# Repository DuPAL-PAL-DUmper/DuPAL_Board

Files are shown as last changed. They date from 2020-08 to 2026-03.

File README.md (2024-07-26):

# DuPAL board

## DISCLAIMER

Any use of this project is **under your own responsibility**.
You will be responsible of checking the correct construction and functionality of your board and the compatiblity of the chips You will insert into it.
By using this project You will agree that I cannot be held responsible if it will destroy any of your devices, damage your computer, burn down your house or whatever.

**Do NOT come to me for hand-holding** using this. It is NOT a plug-and-play tool, and it is something I created **for my own use** and I released in case someone might have an use for it.

## Introduction

The DuPAL boards are tools meant to help in dumping/reversing the content of some PLDs and memories.

The original DuPAL revision 2, currently supported by most tools, but limited in support to PAL devices (with the exclusion of PAL22) can be found [here](https://github.com/DuPAL-PAL-DUmper/DuPAL_Board/tree/master/board/DuPal_DIP).

The [DuPAL V3](https://github.com/DuPAL-PAL-DUmper/DuPAL_Board/tree/master/board/DuPal_V3), AKA "dupico", has more potential and will eventually support a much larger number of devices, but most of the tools have not yet been ported to it. Adapter pods for the dupico can be found [here](https://github.com/DuPAL-PAL-DUmper/DuPAL_Board/tree/master/board/dupico_pods).

### Sponsorship

PCBWay_logo

This project is kindly sponsored by [PCBWay](https://pcbway.com).
PCBWay specializes in manufacturing high-quality PCBs and makes them affordable to hobbyist and professionals alike.

The range of services they offer include PCB prototyping, assembly, instant quotes for your order, a verification process by a team
of experts and an easy to use, hassle-free order process.

I'm grateful to PCBWay for the support in creating this project.

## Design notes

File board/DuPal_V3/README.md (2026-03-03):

# DuPAL V3 "dupico" board

## DISCLAIMER

Any use of this project is **under your own responsibility**.
You will be responsible of checking the correct construction and functionality of your board and the compatiblity of the chips You will insert into it.
By using this project You will agree that I cannot be held responsible if it will destroy any of your devices, damage your computer, burn down your house or whatever.

**Do NOT come to me for hand-holding** using this. It is NOT a plug-and-play tool, and it is something I created **for my own use** and I released in case someone might have an use for it.

## Introduction

The DuPAL V3, AKA "dupico" board is a simple circuit that mounts a Raspberry Pico (RP2040), 74HC595 SIPO registers, 74HCT166 PISO registers, and some glue logic and passives.

The board is designed to help me analyze and dump various types of PLDs and memories.

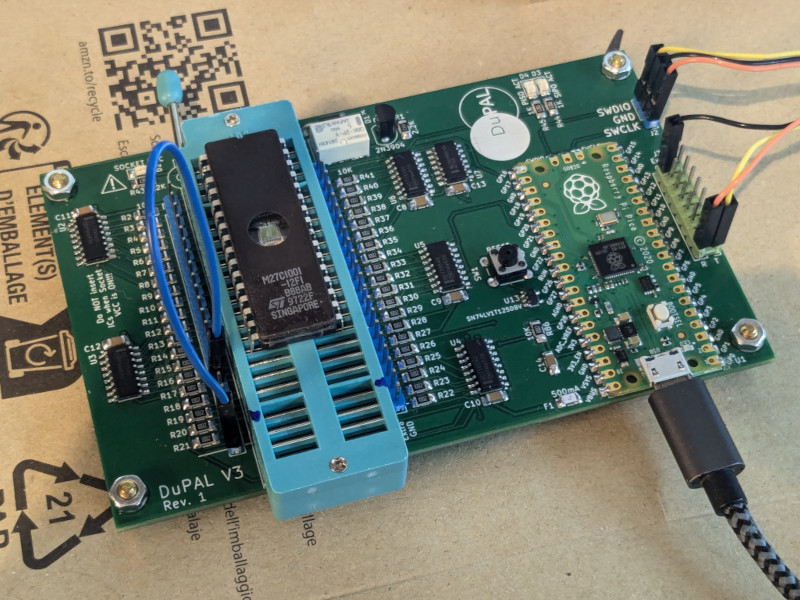
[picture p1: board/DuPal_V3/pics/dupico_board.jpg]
Rev. 1 PCB


Various adapters (or "pods") can be designed to suit different types of ICs. The pods will be plugged in the ZIF42 socket.

## Software

### Firmware

See [here](https://github.com/DuPAL-PAL-DUmper/dupico_firmware) for details.

### dpdumper

This is a generic dumper for combinatorial ICs. See [here](https://github.com/DuPAL-PAL-DUmper/dpdumper) for the repository.

## Hardware

The board was designed with [KiCad](https://kicad.org/) EDA.

In its current form, the board is relatively simple build, using through-hole and (non fine pitched) SMD components.

### Bill of Materials

| Component | Qty | Type / Value | Notes |
| --- | --- | --- | --- |
| C1, C3 - C14 | 13  | 100nF / 1206 / ceramic | |
| C2 |  1  | 10uF / 10V / 1206 / ceramic | |
| D1 |  1  | 1N5818 | |
| D2, D3, D4 |  3  | Your choice of 1206 SMD LEDs | |
| F1 |  1  | 1206 500mA fuse | https://www.mouser.it/ProductDetail/530-C1F500 |
| J1 |  1  | ZIF42 or ZIF48 socket, wide | If using ZIF42, leave the bottom 6 pins empty on the PCB |
| J2 |  1  | 1x3 header, 2.54mm pitch | |
| J3 |  1  | 2x8 header, 2.54mm pitch | |
| J4, J5 |  2  | 1x21 header, 2.54mm pitch | |
| K1 |  1  | Omron G6K-2P-Y-DC5 | https://www.mouser.it/ProductDetail/653-G6K-2P-Y-DC5 |
| Q1 |  1  | 2N3904 | |
| R1 |  1  | 2.2K / 1206 | |
| R2 - R41, R86 | 41  | 10K / 1206 | |
| R42, R46 - R85 | 41  | 470K / 1206 | |
| R43 - R45 |  3  | 1.2K / 1206 | |
| SW1 |  1  | Switch button 6mm | |
| U1 |  1  | Pi Pico | |
| U2 - U6 |  5  | 74HCT595 SOIC-16 | HCT variant is important |
| U7 |  1  | 74HCT02 SOIC-14 | HCT variant is important |
| U8 - U12 |  5  | 74HCT166 SOIC-16 | HCT variant is important |
| U13 |  1  | SN74LV1T125DBV SOT-23-5 | https://www.mouser.it/ProductDetail/595-74LV1T125DBVRG4  |

⚠️**WARNING:**⚠️ Note that U10, on the backside of the PCB, has the opposite orientation in respect to U8, U9, U11 and U12. This is NOT a mistake, trust the silkscreen in this case.

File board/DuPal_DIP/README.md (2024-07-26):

# DuPAL board

## DISCLAIMER

Any use of this project is **under your own responsibility**.
You will be responsible of checking the correct construction and functionality of your board and the compatiblity of the chips You will insert into it.
By using this project You will agree that I cannot be held responsible if it will destroy any of your devices, damage your computer, burn down your house or whatever.

**Do NOT come to me for hand-holding** using this. It is NOT a plug-and-play tool, and it is something I created **for my own use** and I released in case someone might have an use for it.

## Introduction

The DuPAL board is a simple circuit that mounts an AVR MCU (A classic ATmega328P of Arduino fame), three 74HC595 SIPO registers, one 74HCT166 PISO register, a MAX232 to adapt the serial port to RS232, a linear voltage regulator and a bunch of other passive components.

This board was designed and built to help myself bruteforce PAL devices. It has the hardware facilities necessary to scan all the inputs of the PAL, to check whether an output is high, low or hi-z and to report back the status to the host.

Details on how the features are implemented can be found on the Firmware's repository.

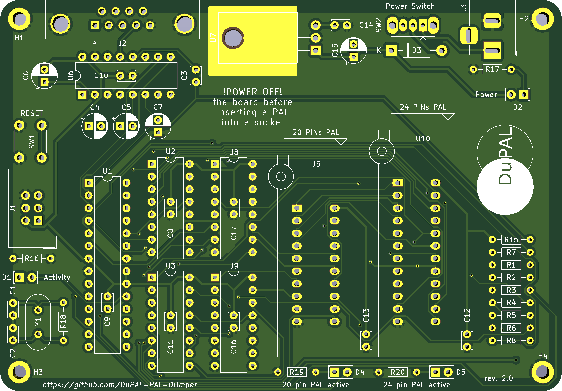
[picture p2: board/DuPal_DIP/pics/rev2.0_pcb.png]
Rev. 2.0 PCB


## Software

### Bootloader

This board uses the [Optiboot Bootloader](https://github.com/Optiboot/optiboot), currently at version 8.0, built for an **ATMega328** running at 20Mhz, and with a baudrate of 57600bps.

The command line to build the bootloader is

```shell
make atmega328 AVR_FREQ=20000000L LED_START_FLASHES=8 BAUD_RATE=57600
```

See [Compiling Optiboot](https://github.com/Optiboot/optiboot/wiki/CompilingOptiboot) for details.

The resulting bootloader can then be loaded via the ISP header. For example, by using `avrdude` and an **AVR Dragon** programmer:

```shell
avrdude  -c dragon_isp -P usb \
  -p atmega328p -e -u -U efuse:w:0xFD:m -U hfuse:w:0xDE:m \
  -U lfuse:w:0xFF:m -U flash:w:optiboot_atmega328.hex
```

### Firmware

Details on the firmware can be found on the **DuPAL_Firmware** repository.

## Hardware

The board was designed with [KiCad](https://kicad.org/) EDA.

In its current form, the board is a pretty simple build, using exclusively through-hole components.

### Powering the board

The board can be powered with a DC supply voltage between 7.5V and 9V, 12V is possible but the regulator starts to get hot.

The power connector has a positive tip, and is protected against reverse voltage by a 1N4001 diode.

### Bill of Materials

- **SW2** - Sliding SPST switch, pin spacing is 2mm, the outer 2 pins are just for mechanical stability
- **J1** - 3x2 pins 2.54mm pcb male header
- **C4, C5, C6 & C7** - 4x 1uF / 35v min electrolytic capacitors
- **C15** - 1x 0.22uF / 35v min electrolytic capacitor
- **C3, C8, C9, C10, C11, C12, C13, C14, C16, C17** - 10x 100nF ceramic bypass capacitors
- **C1 & C2** - 2x 22pF NP0 ceramic capacitors
- **R18** - 1x 1Mohm 1/4W resistor
- **R17** - 1x 1.2k 1/4W resistor
- **R16, R19 & R20** - 3x 680ohm 1/4W resistor
- **R1, R2, R3, R4, R5, R6, R7, R8 & R15**, 9x 10Kohm 1/4W resistors
- **D1, D2, D4 & D5** - 4x 3mm LED (recommended red for power, green for activity)
- **J3** - Power supply female barrel connector
- **J2** - DB9 female angled connector
- **SW1** - 4 pin push button
- **D3** - 1N4001 diode
- **U2, U3 & U9** - 3x 74HC595
- **U8** - 1x 74HCT166
- **U6** - MAX232
- **U7** - 7805 TO220 regulator
- **U1** - ATMega328p
- **Y1** - 20Mhz HC49 crystal
- **U5** - 20pin slim ZIF socket
- **U10** - 24pin slim ZIF socket
- *Heat sink for the power regulator (optional, but recommended)*
- *5x 16pin socket (optional)*
- *1x 28pin slim socket (optional)*

Thanks @Porchy for the updated BOM.

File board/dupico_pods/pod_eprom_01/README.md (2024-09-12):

# EPROM_01 POD for dupico

## DISCLAIMER

Any use of this project is **under your own responsibility**.
You will be responsible of checking the correct construction and functionality of your board and the compatiblity of the chips You will insert into it.
By using this project You will agree that I cannot be held responsible if it will destroy any of your devices, damage your computer, burn down your house or whatever.

**Do NOT come to me for hand-holding** using this. It is NOT a plug-and-play tool, and it is something I created **for my own use** and I released in case someone might have an use for it.

## Introduction

The EPROM_01 POD is an adapter for the DuPAL V3 (AKA "dupico") meant to support the most common 24/28/32 pin ROMs, the only requirement being that they can be powered by 5V, have GND in the lower left pin and VCC in the upper right.

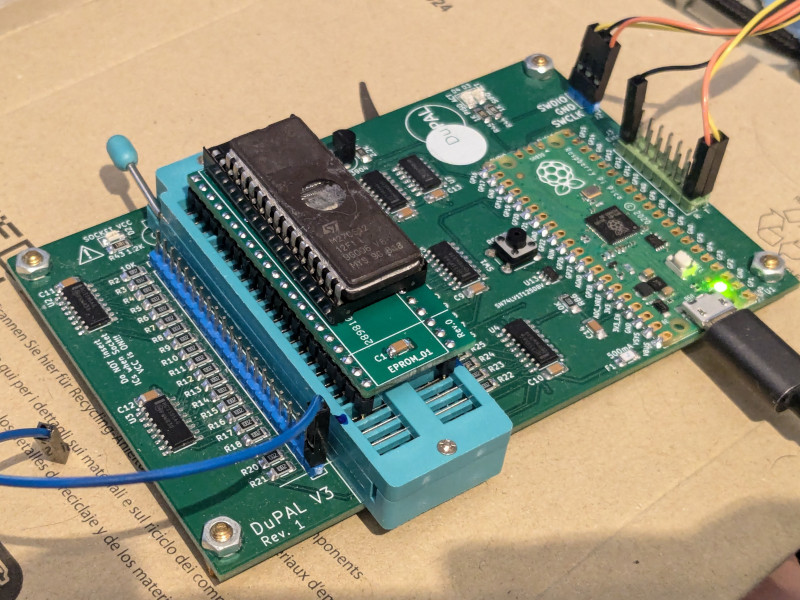
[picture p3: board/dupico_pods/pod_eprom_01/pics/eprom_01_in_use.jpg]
Rev. 0 PCB


### Usage

This device is inserted in the ZIF socket of the dupico: if you installed a ZIF42 socket, it will fill all the 42 pins, if you installed a 48 pin socket, make sure to leave the bottom 6 pins empty (fit this in the topmost part of the socket).

When you fit a ROM device in it, make sure to align it to the bottom of the pod socket (so, a 28 pin device will leave empty the topmost 4 pins in the socket). 

Pin 32 on the pod socket is **hardwired to VCC**, there are other 7 selectable pins that can provide power, configured with 3 pins on the **ZIF42** socket:

| 24 | 23 | 22 | -> | Powered Pin (32 pin socket) |
| -- | -- | -- | -- | --- |
|  0 |  0 |  0 | | 30 / 32 |
|  0 |  0 |  1 | | 28 / 32 |
|  0 |  1 |  0 | | 26 / 32 |
|  0 |  1 |  1 | | 25 / 32 |
|  1 |  0 |  0 | | 24 / 32 |
|  1 |  0 |  1 | | 23 / 32 |
|  1 |  1 |  0 | | 20 / 32 |
|  1 |  1 |  1 | | 32 only |

#### Socket connections

This drawing shows how the pin on the 32 socket are wired to the pins on the dupico's ZIF42.

```
            __ __
   1 ---> 1   U  32 <--- +5V (fixed)
   2 ---> 2      31 <-- 41
   3 ---> 3      30 <-- 40 --- Selectable +5V
   4 ---> 4      29 <-- 39
   5 ---> 5      28 <-- 38 --- Selectable +5V
   6 ---> 6      27 <-- 37
   7 ---> 7      26 <-- 36 --- Selectable +5V
   8 ---> 8      25 <-- 35 --- Selectable +5V
   9 ---> 9      24 <-- 34 --- Selectable +5V
  10 --> 10      23 <-- 33 --- Selectable +5V
  11 --> 11      22 <-- 32
  12 --->12      21 <-- 31
  13 --> 13      20 <-- 30 --- Selectable +5V
  14 --> 14      19 <-- 29
  15 --->15      18 <-- 28
GND ---> 16______17 <-- 27

```

## Hardware

The board was designed with [KiCad](https://kicad.org/) EDA.

In its current form, the board is relatively simple build, using through-hole and (non fine pitched) SMD components.

You can order the PCBs at [PCBWay](https://www.pcbway.com/project/shareproject/dupico_EPROM_01_POD_ed82b51c.html)!

### Bill of Materials

| Component | Qty | Type / Value | Notes |
| --- | --- | --- | --- |
| J1 |  2  | 21 pin 2.54mm headers | Use rounded pin headers to put less stress on dupico ZIF, snip the protruding part of the header |
| C1, C2 |  2  | 100nF / 1206 / ceramic | |
| Q1 - Q7 |  7  | MMBT3906 | |
| J2 |  1  | 32 pin wide socket | Solder this AFTER the two J1 headers, you can use a ZIF32 socket. |
| U2 |  1  | 74ACT138 SOIC-16 | |
| R1 - R7 |  7  | 1K / 1206 | |

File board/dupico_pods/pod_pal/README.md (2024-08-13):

# PAL POD for dupico

## DISCLAIMER

Any use of this project is **under your own responsibility**.
You will be responsible of checking the correct construction and functionality of your board and the compatiblity of the chips You will insert into it.
By using this project You will agree that I cannot be held responsible if it will destroy any of your devices, damage your computer, burn down your house or whatever.

**Do NOT come to me for hand-holding** using this. It is NOT a plug-and-play tool, and it is something I created **for my own use** and I released in case someone might have an use for it.

## Introduction

The PAL POD is an adapter for the DuPAL V3 (AKA "dupico") meant to support 20 and 24 pin PAL (and pinout compatible) devices.

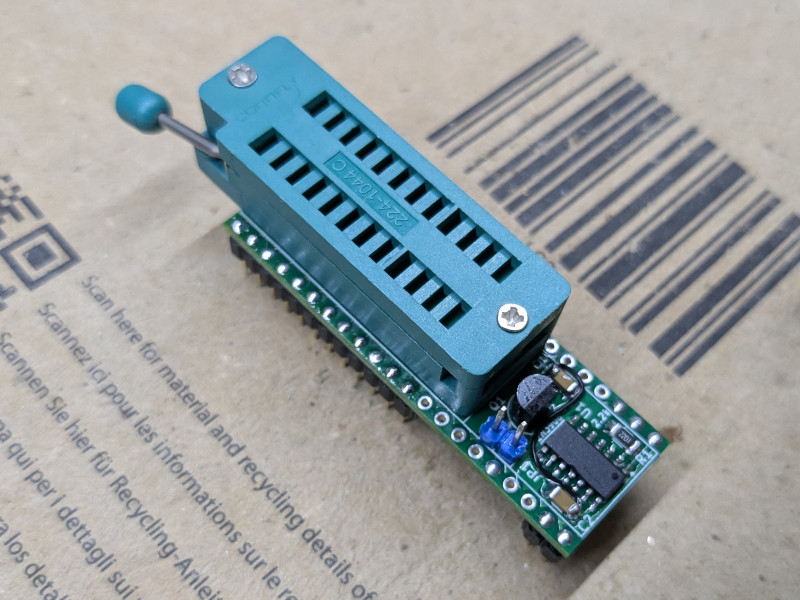
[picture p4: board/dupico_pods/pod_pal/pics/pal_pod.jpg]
Rev. 0 PCB


### Usage

This device is inserted in the ZIF socket of the dupico: if you installed a ZIF42 socket, it will fill all the 42 pins, if you installed a 48 pin socket, make sure to leave the bottom 6 pins empty (fit this in the topmost part of the socket).

When you fit a PAL device in it, make sure to align it to the bottom of the ZIF24 socket (so, a 20 pin device will leave empty the topmost 4 pins in the socket). 

**Pulling high pin 22 of the ZIF42 socket will turn on the transistor on the pod, which in turn will provide 5V to pin 22 of the ZIF24 socket**, pin 12 is hardwired to GND, and pin 24 to VCC.

Some old PAL/GAL devices require more current than the switching via pin 22 can provide. In these cases, close JP1 to bypass the transistor and provide 5V directly.

#### Socket connections

This drawing shows how the pin on the ZIF24 sockets are wired to the pins on the dupico's ZIF42.

```
            __ __
   1 ---> 1   U  24 <--- +5V
   2 ---> 2      23 <-- 41
   3 ---> 3      22 <-- 40 --- 5V if ZIF42 pin 22 is HIGH
   4 ---> 4      21 <-- 39     or JP1 closed
   5 ---> 5      20 <-- 38
   6 ---> 6      19 <-- 37
   7 ---> 7      18 <-- 36
   8 ---> 8      17 <-- 35
   9 ---> 9      16 <-- 34
  10 --> 10      15 <-- 33
  11 --> 11      14 <-- 32
GND ---> 12______13 <-- 31

```

## Hardware

The board was designed with [KiCad](https://kicad.org/) EDA.

In its current form, the board is relatively simple build, using through-hole and (non fine pitched) SMD components.

You can order the PCBs at [PCBWay](https://www.pcbway.com/project/shareproject/dupico_PAL_POD_06ceb24f.html)!

### Bill of Materials

| Component | Qty | Type / Value | Notes |
| --- | --- | --- | --- |
| J1 |  2  | 21 pin 2.54mm headers | Use rounded pin headers to put less stress on dupico ZIF |
| C1, C2 |  2  | 100nF / 1206 / ceramic | |
| JP1 |  1  | 2 pin 2.54mm header | Bypasses the transistor and provides direct 5V |
| Q1 |  1  | 2N3906 TO92 | |
| J2 |  1  | narrow ZIF24 socket | Solder this AFTER the two J1 headers |
| U1 |  1  | 74ACT04 SOIC-14 | |
| R1 |  1  | 1K / 1206 | |

If you wish to use a 74HCT04 for U1, use a 2.2K resistor for R1.

## Errata

- Rev. 0 requires a bodge wire, see changelog for details
- Rev. 0 and 1 have the footprint of 2N3906 reversed. With these revisions, you need to rotate the transistor in respect to the footprint!

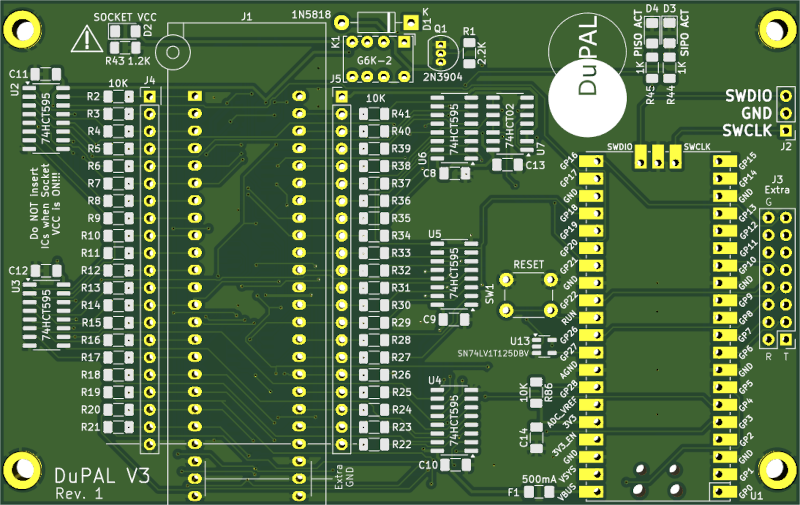
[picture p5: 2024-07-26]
board/DuPal_V3/pics/rev_1.png

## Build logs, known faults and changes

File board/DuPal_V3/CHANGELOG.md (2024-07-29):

# Board Revisions

## Rev. 2

No changes in schematic, rerouted some traces to avoid clearance violations.

## Rev. 1

First released design

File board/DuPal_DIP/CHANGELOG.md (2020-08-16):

# Board Revisions

## Rev. 2.0 (2020-08-??)

- Added support for 24 pin PALs
- Use shift registers for input
- Added LEDs to indicate activity on a socket

Rev. 2.0 PCB

## Rev. 1.1 (2020-08-15)

- Fixed the ugly silkscreen from rev.1

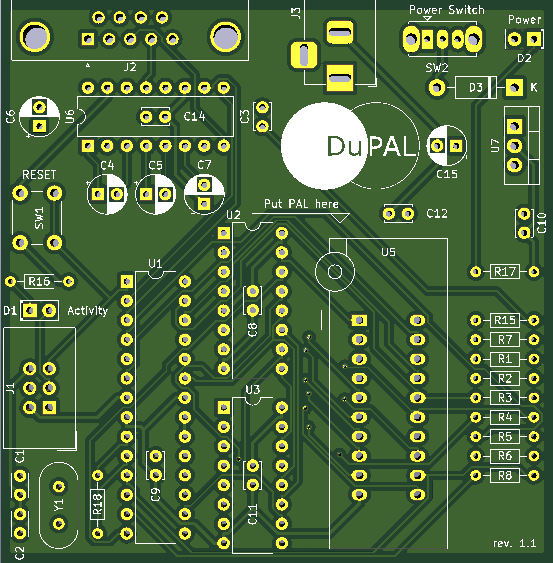
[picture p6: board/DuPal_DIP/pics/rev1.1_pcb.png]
Rev. 1.1 PCB


## Rev. 1 (2020-??-??)

First produced  version of the board, recognizable by a "rev.1" on the bottom right corner.

- Supports 20 pin PAL devices
- RS232 interfacing

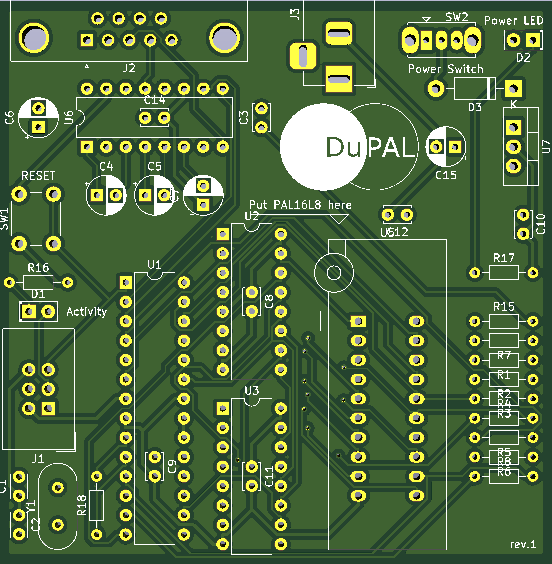
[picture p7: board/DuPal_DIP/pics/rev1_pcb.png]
Rev. 1 PCB


## Rev. 0 (2019-??-??)

First design, was never produced. Had some ICs too near to actually fit.

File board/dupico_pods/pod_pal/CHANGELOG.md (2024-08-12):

# PAL pod for Dupico

## Rev. 2

- Replaced R1 with 1K resistor
- Replaced 74HCT04 with 74ACT04
- Fixed 2N3906 orientation

## Rev. 1

- Fixed missing VCC trace 
- **WARNING:** 2N3906 is reversed!

## Rev. 0 - Initial release

- Initial release of the card
- Has a missing VCC trace to power the IC
- **WARNING:** 2N3906 is reversed!

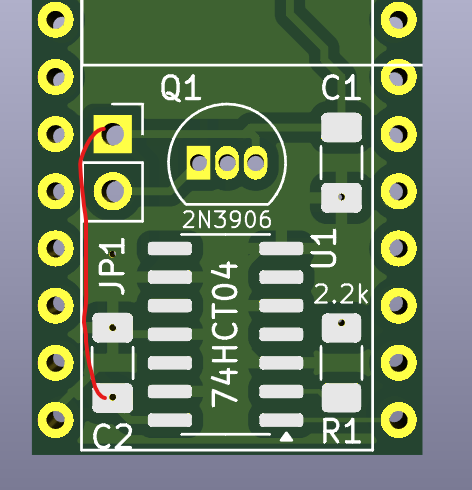
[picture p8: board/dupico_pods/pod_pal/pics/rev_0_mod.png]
Rev.0 Mod


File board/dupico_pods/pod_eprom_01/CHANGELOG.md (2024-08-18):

# EPROM_01 pod for Dupico

## Rev. 0 - Initial release

- Initial release of the card

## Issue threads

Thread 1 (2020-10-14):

Wrong Capacitor

toms001, 2020-10-14:
Hi, a very cool project!
1x 0.22uF / 35v min electrolytic capacitor (bom) at the 7805 or 220uF?
Thanks, toms001

hkzlab, 2020-10-14:
Hello, it's 0.22, but is also actually a non-critical value, as it is meant to smooth out the ingress from your power supply.
I myself used a 0.22uF in a build and a 0.47 in another because I had that one handy.
By all means, if you have a noisy psu increase it, even to 100uF if required.

toms001, 2020-10-19:
ok, thank you. A last question about the 74HC(T) - does it matter if i choose 74HC or 74HCT? In the schematics there is a 74HC166 and at your bom is 74HCT166 listed.

hkzlab, 2020-10-19:
Use an HCT for the 166, outputs from PALs that have TTL level signals will be picked up better.
You can use HC for the rest.

Closed 2020-10-14.

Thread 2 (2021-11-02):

Some issues with capacitors

dillix, 2021-11-02:
Hi, hkzlab! Thanks for cool project!

There is some issues with capacitors:
1) There is C5 electrolytic capacitor in BOM list. Can you provide it capacity?
2) I tried several types of through-hole ceramic bypass capacitors 100nF (C3, C8, C9, C10, C11, C12, C13, C14, C16, C17) , but all of them didn't fit under the cribs for chips, so I soldered smd ones. Can you provide a photo of your ones?

hkzlab, 2021-11-02:
Fixed missing C5. Use an 1uF. If in doubt, refer to the schematics in the kicad project.

For the 100nF caps, either
- Find sockets with a larger space in the middle
- Mount them on the underside of the board.

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

Closed 2021-11-02.

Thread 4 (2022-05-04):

Specifications for the switch

hexbus, 2022-05-04:
Greetings - do you have the specifications for the required switch?  i.e. spacing between pins, etc?

V/R,
Jon

hkzlab, 2022-05-05:
I can't give you a model: I've designed it to use some junk no-name switches I had around, though it should be pretty standard:
The pitch between the holes is 2mm.
Only the center and right inner pins are used and connected (looking at the board from the component side, keeping the power switch component up), the rest is for support.
So if you find a switch that fits on the external holes and the center one, just put a blob of solder to connect the outer support pins with the nearest smaller pad of the inner pins.

hexbus, 2022-05-05:
Great, that spacing helps me out quite a bit!  If you could please add the 2MM description to the BOM, I’ll let you know when I find a switch that works and give you the model!  Thanks!

hexbus, 2022-05-09:
I've found a few that work:

[First one from DigiKey - right angle](https://www.digikey.com/en/products/detail/c&k/OS102011MA1QN1/1981430)

[Second one from DigiKey - straight](https://www.digikey.com/en/products/detail/c-k/OS102011MS2QN1/411602)

These are both rated for 12V, but only .1A.  Not sure how much current is going through this switch - do you have any thoughts as to the specs?

I also found a bunch of these for cheap [on eBay](https://www.ebay.com/itm/182535742300).  Same switch, apparently.

hkzlab, 2022-05-10:
Hm, the component that will absorb the most, by far, will be the PAL you put on the board. I took some measurements years ago, but it seems I can't find where I put the notes. Current was usually slightly above the 100mA mark though.
Alas, none of the junk switches I used had markings on them.

You can also use the two external support units to connect the switch (4mm pitch) if you can't find something rated 0.2A, they're not connected to GND. You just need to put a blob of solder between the outer and the inner pins to restore connection (I actually did that on one of my protos).

Also, I usually use a lower voltage than 12, 7 or 8VDC is fine.

hexbus, 2022-05-10:
Yeah, the eBay ones I found didn’t have any marking either.  I’ll have to see how well it works :-)

I agree we need something more slightly beefier than a 0.1.  I’ll need to burn a protected PAL/GAL and see if the noname eBay switch holds up.

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

JohnDMcMaster, 2022-05-16:
I just went through a build exercise and could submit a reference BOM if it was accepted into the README

WIP can be seen here: https://twitter.com/johndmcmaster/status/1525758218961440768

hkzlab, 2022-05-16:
@JohnDMcMaster sure. Absolutely nothing against that.
Especially since life is really hectic for me now, so can't really work on this anymore for the foreseeable future, so every help is gladly accepted.

Closed 2022-11-08.

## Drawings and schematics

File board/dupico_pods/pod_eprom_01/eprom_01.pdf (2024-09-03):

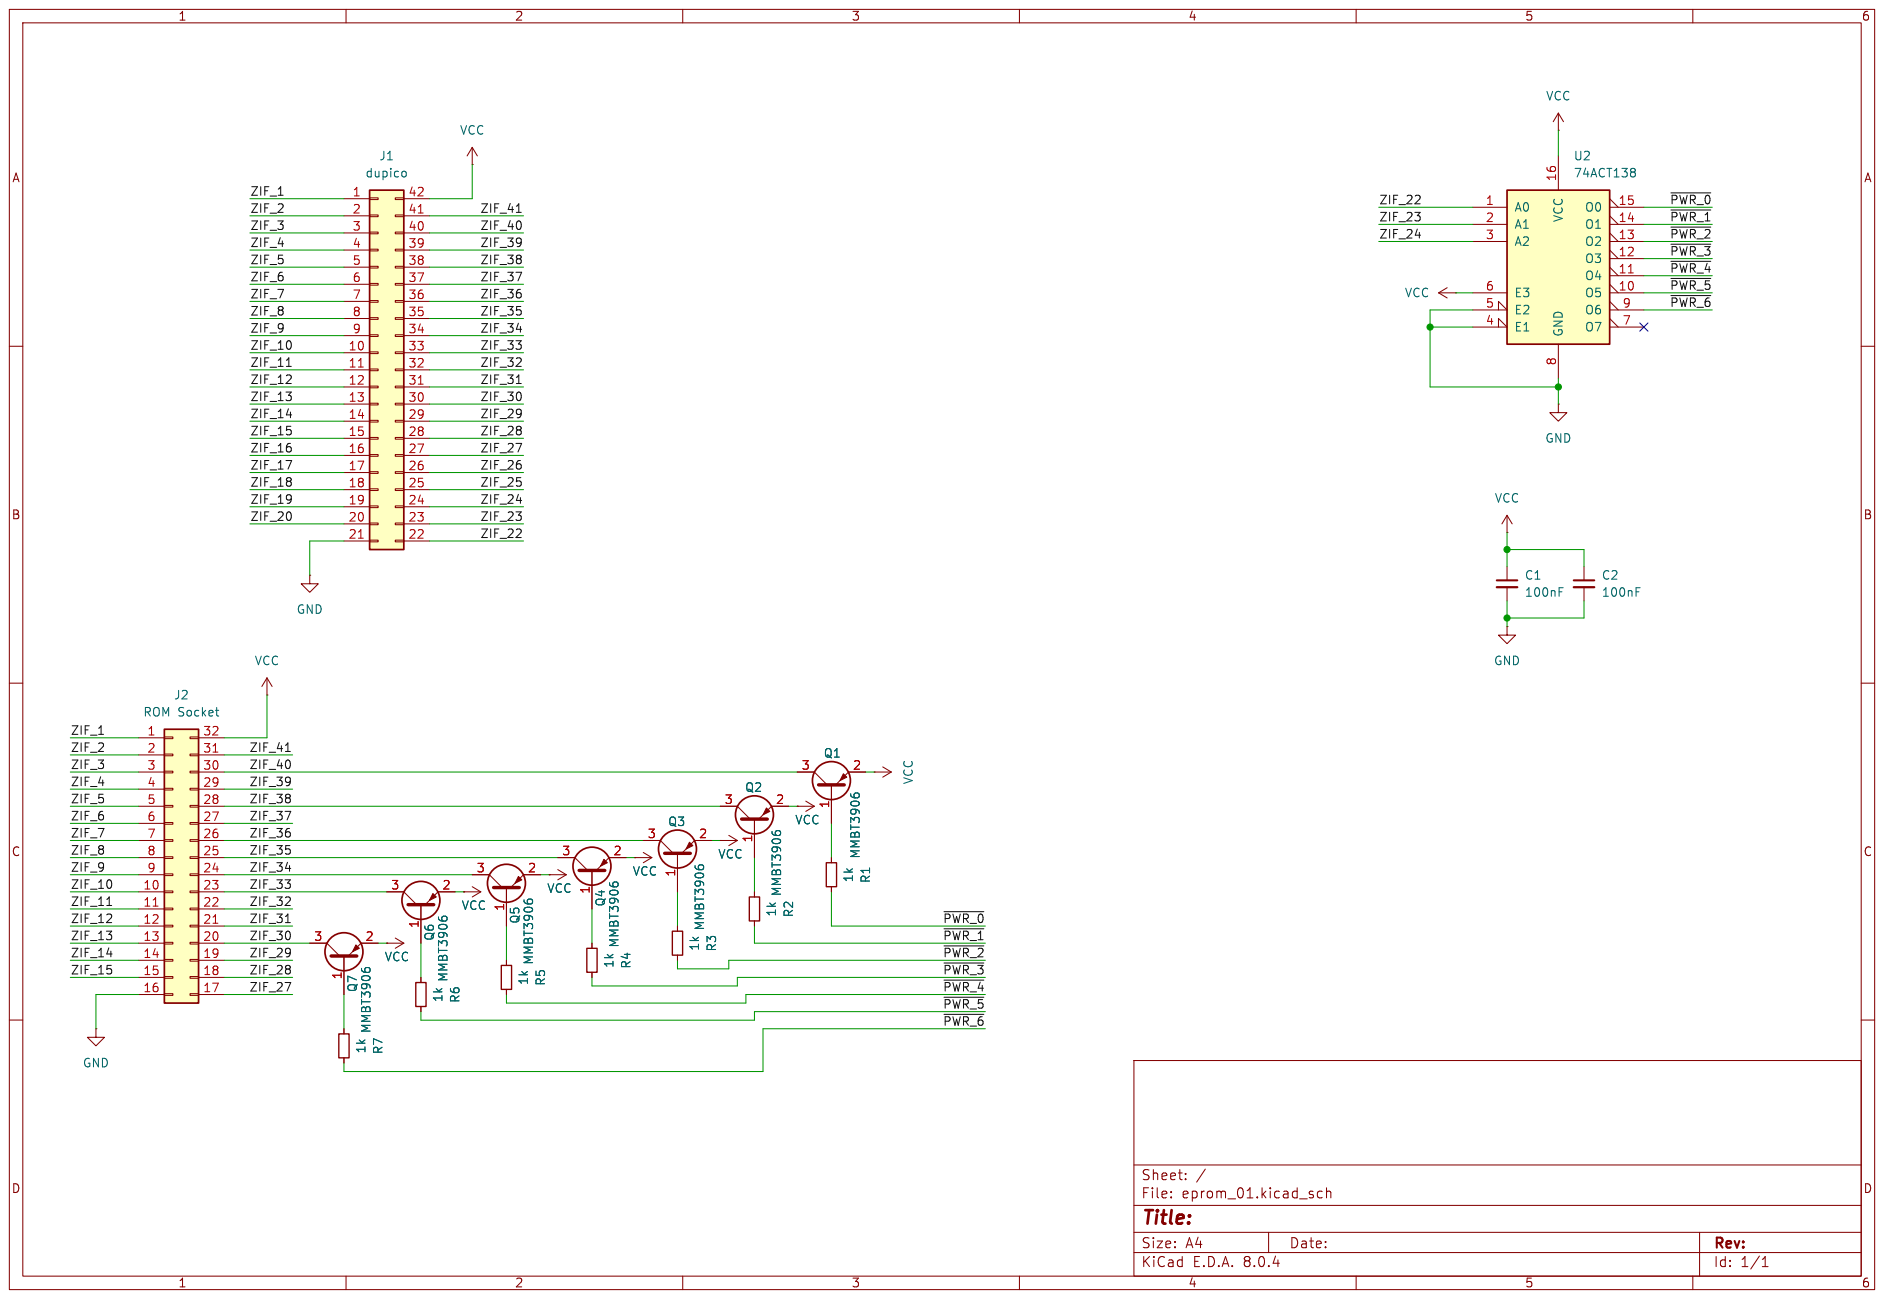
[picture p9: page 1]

Id: 1/1 Title: File: eprom_01.kicad_sch Sheet: / 1kR1

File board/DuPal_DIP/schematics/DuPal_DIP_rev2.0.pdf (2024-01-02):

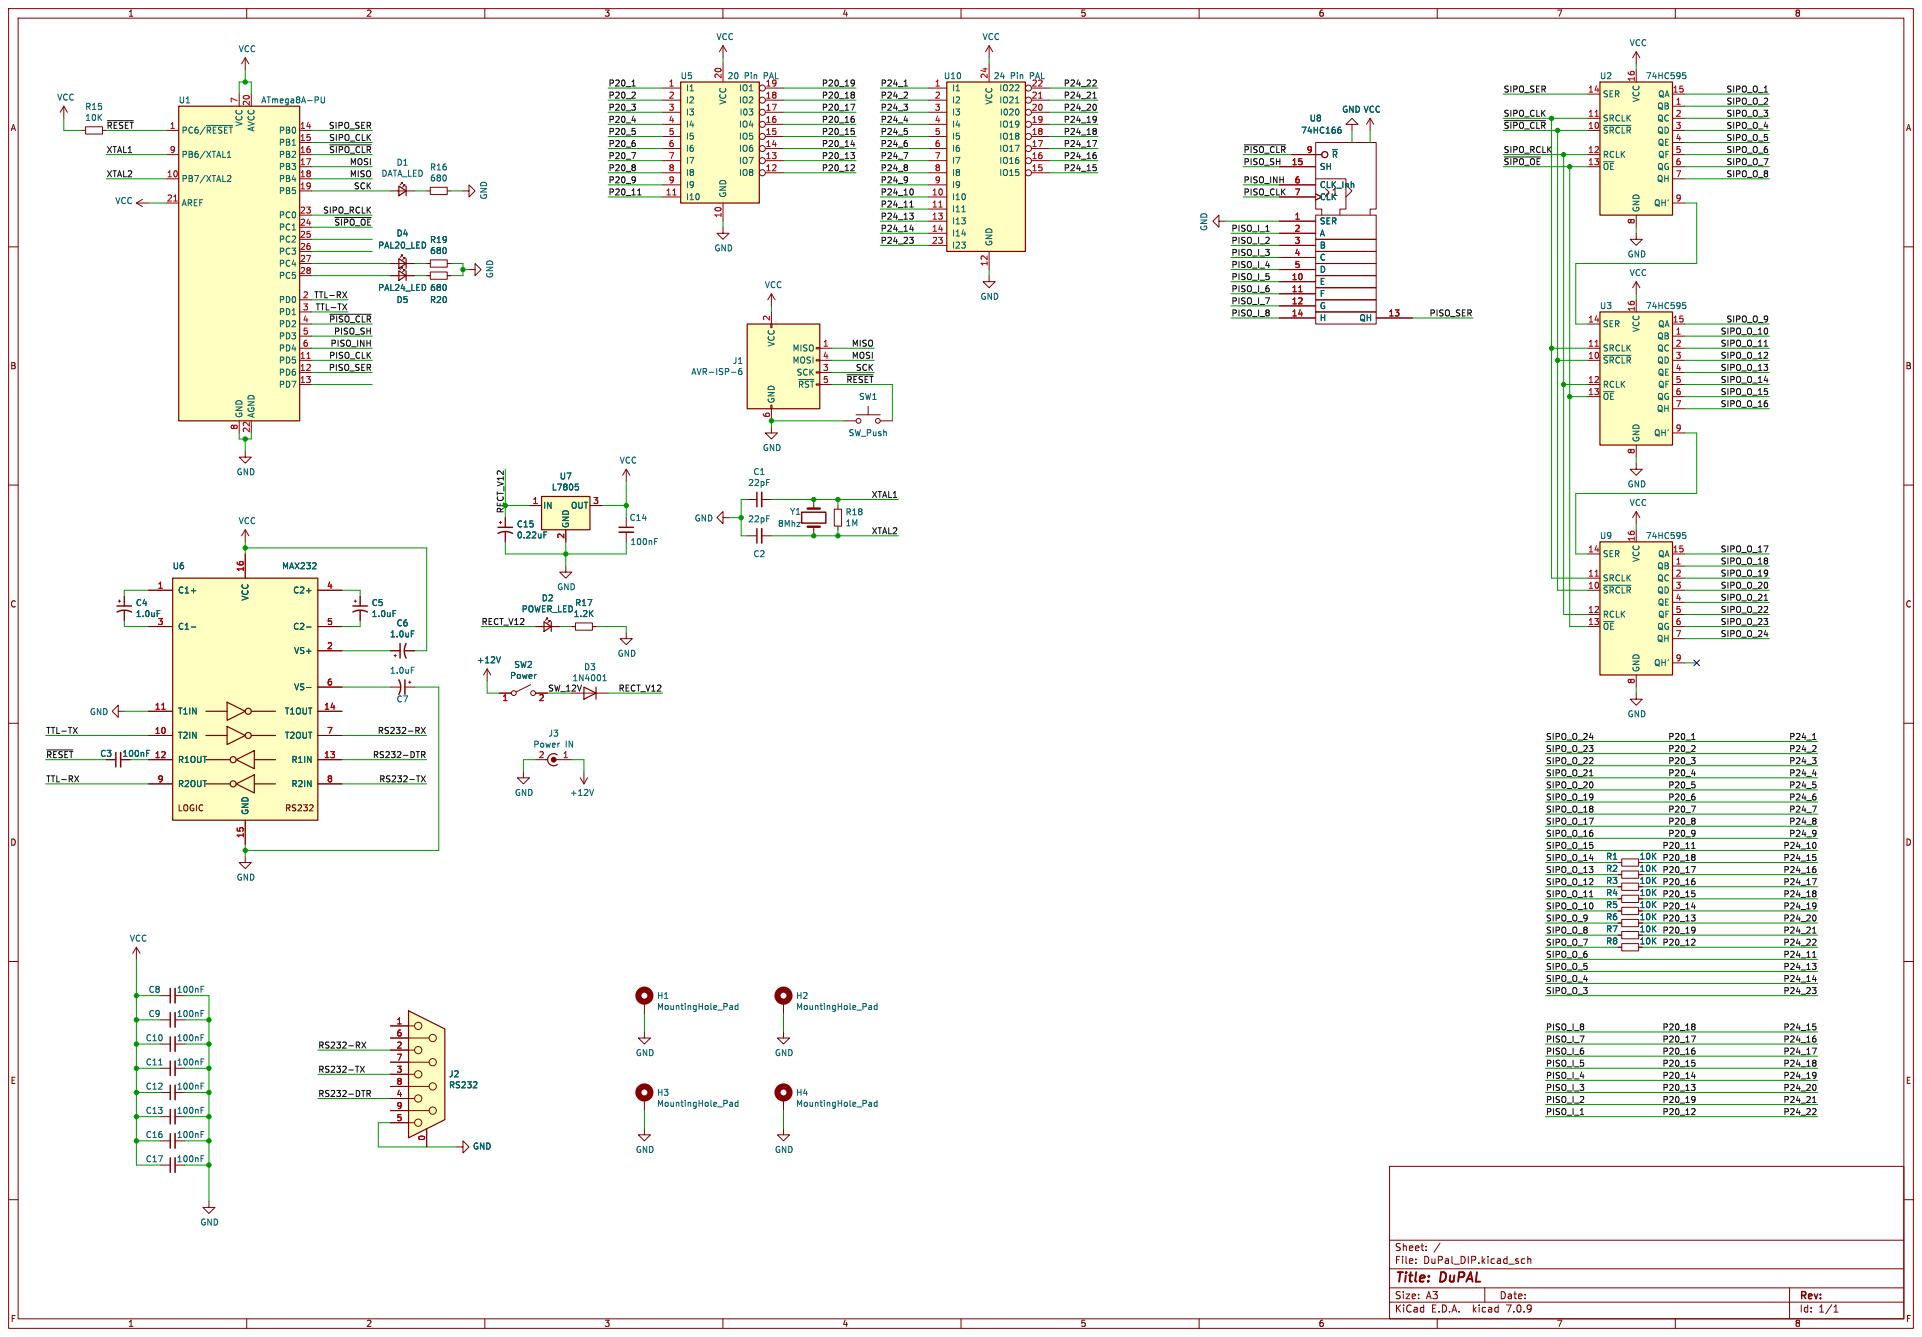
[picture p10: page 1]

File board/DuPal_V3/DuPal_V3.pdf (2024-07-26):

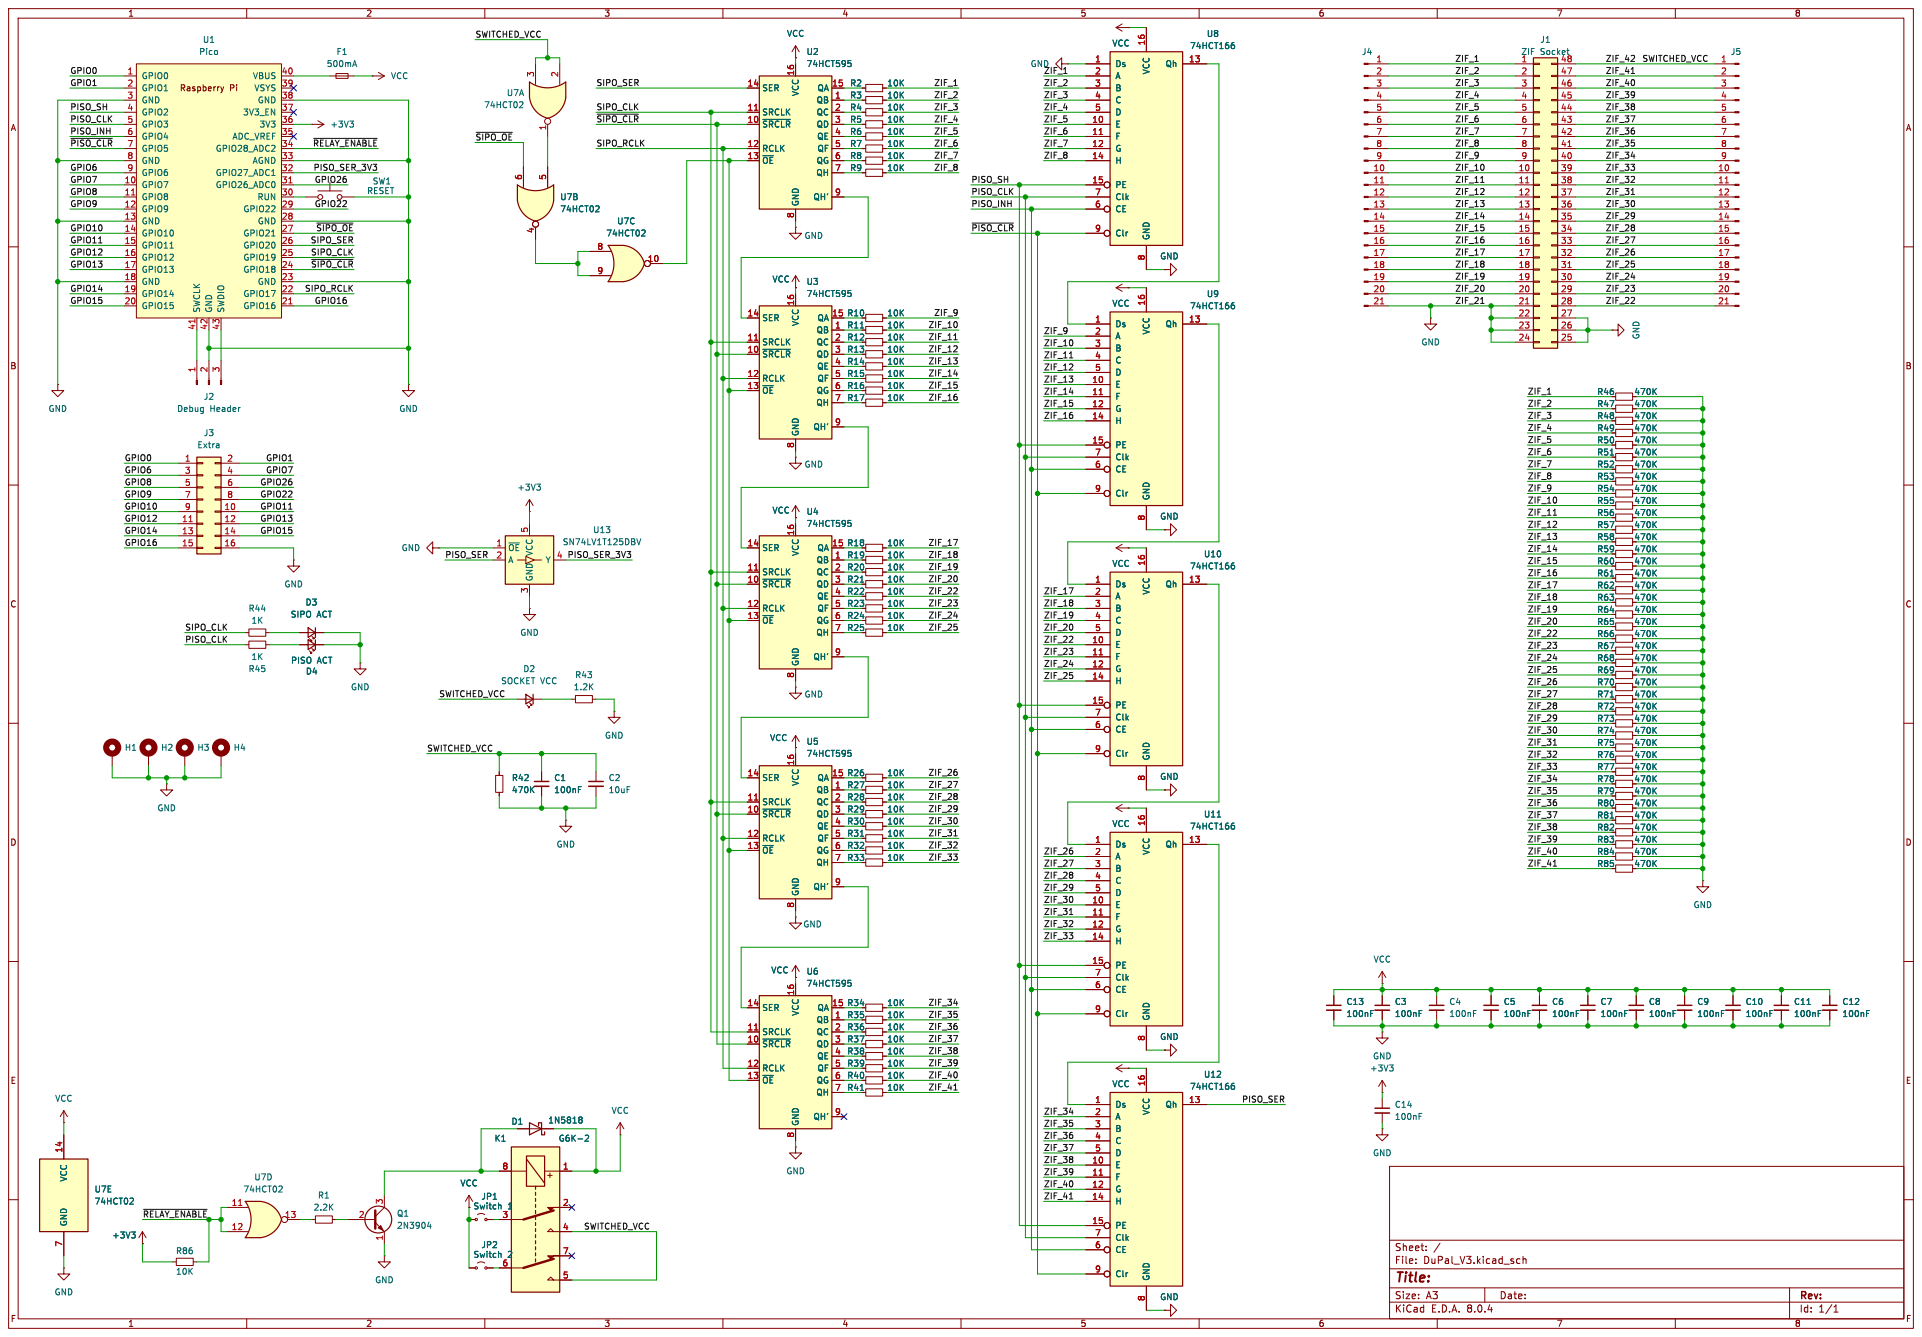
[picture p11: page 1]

470K D4 PISO ACT D3 SIPO ACT

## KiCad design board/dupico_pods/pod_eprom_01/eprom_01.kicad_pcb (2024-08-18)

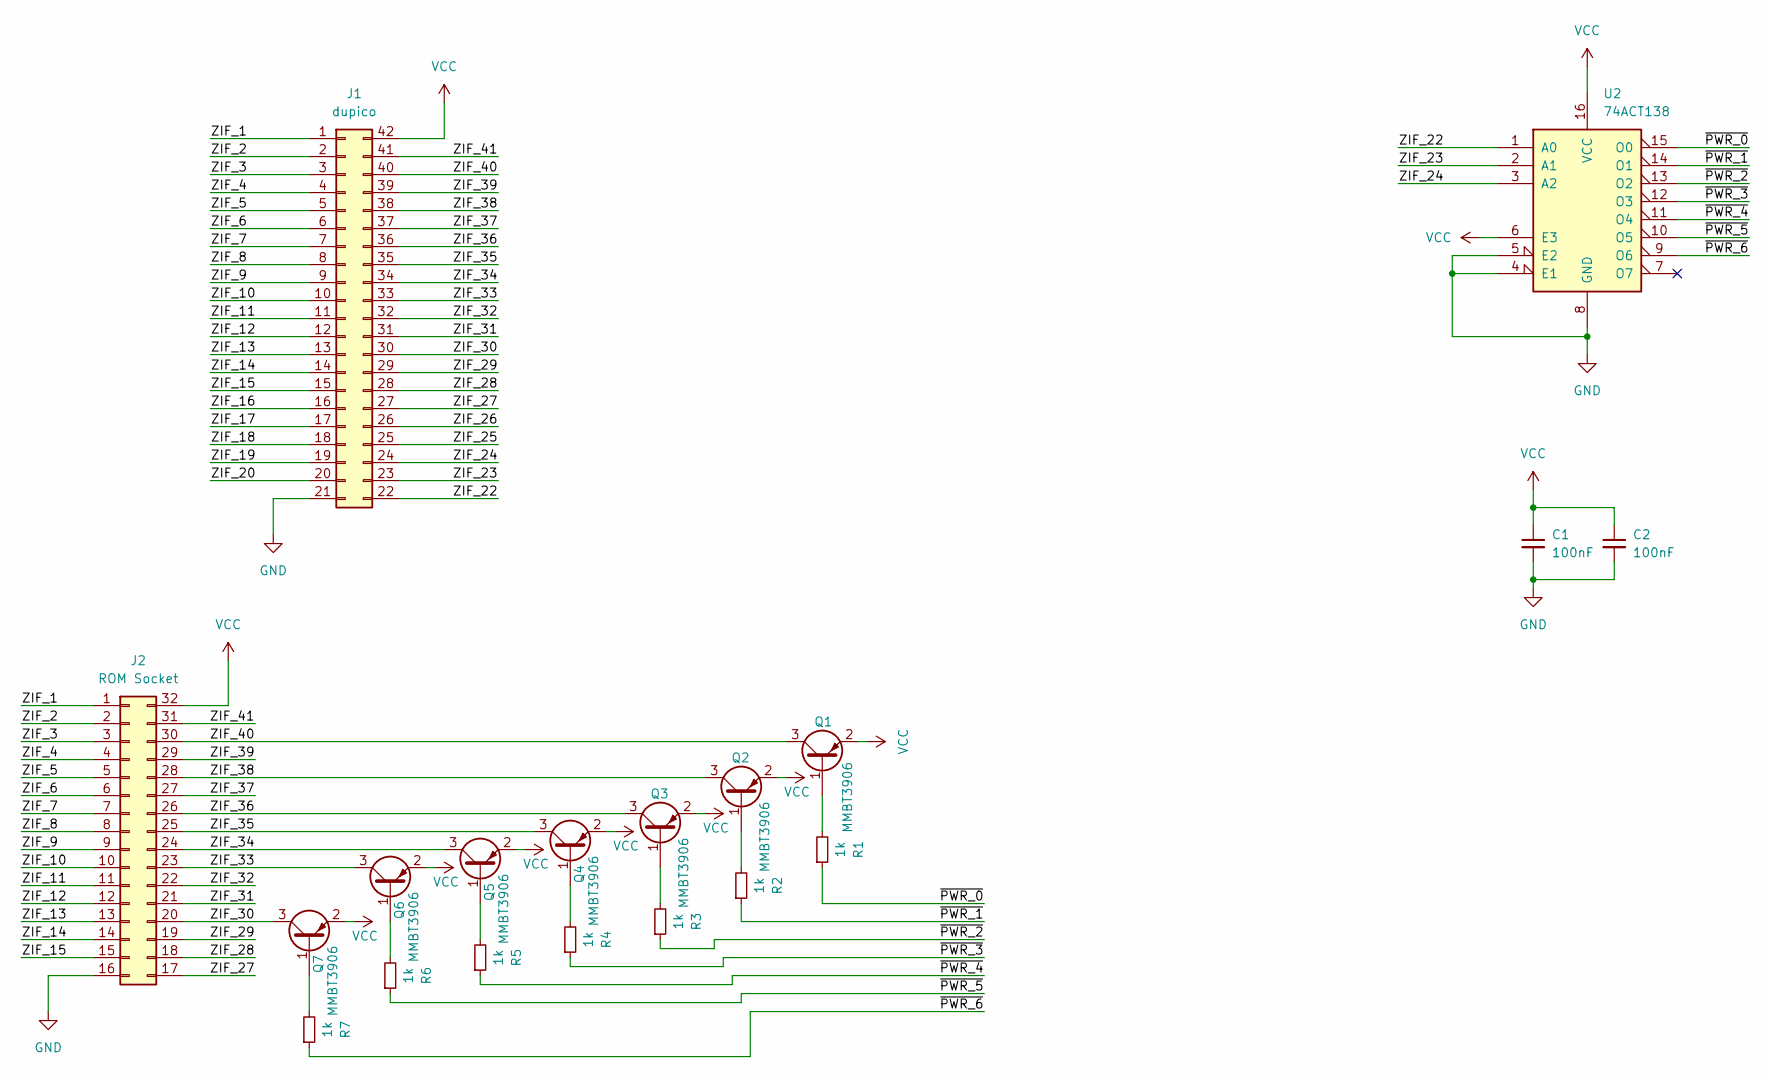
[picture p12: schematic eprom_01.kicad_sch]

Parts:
C1, C2: 100nF; C_1206_3216Metric_Pad1.33x1.80mm_HandSolder
J1: dupico; DIP-42_W15.24mm
J2: ROM Socket; DIP_Socket-32_W11.9_W12.7_W15.24_W17.78_W18.5_3M_232-1285-0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
Q1, Q2, Q3, Q4, Q5, Q6, Q7: MMBT3906; SOT-23
R1, R2, R3, R4, R5, R6, R7: 1k; R_1206_3216Metric_Pad1.30x1.75mm_HandSolder
U2: 74ACT138; SOIC-16_3.9x9.9mm_P1.27mm

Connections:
/ZIF_1: J1.1, J2.1
/ZIF_2: J1.2, J2.2
/ZIF_3: J1.3, J2.3
/ZIF_4: J1.4, J2.4
/ZIF_5: J1.5, J2.5
/ZIF_6: J1.6, J2.6
/ZIF_7: J1.7, J2.7
/ZIF_8: J1.8, J2.8
/ZIF_9: J1.9, J2.9
/ZIF_10: J1.10, J2.10
/ZIF_11: J1.11, J2.11
/ZIF_12: J1.12, J2.12
/ZIF_13: J1.13, J2.13
/ZIF_14: J1.14, J2.14
/ZIF_15: J1.15, J2.15
/ZIF_16: J1.16
/ZIF_17: J1.17
/ZIF_18: J1.18
/ZIF_19: J1.19
/ZIF_20: J1.20
/ZIF_22: J1.22, U2.1 (A0)
/ZIF_23: J1.23, U2.2 (A1)
/ZIF_24: J1.24, U2.3 (A2)
/ZIF_25: J1.25
/ZIF_26: J1.26
/ZIF_27: J1.27, J2.17
/ZIF_28: J1.28, J2.18
/ZIF_29: J1.29, J2.19
/ZIF_30: J1.30, J2.20, Q7.3 (C)
/ZIF_31: J1.31, J2.21
/ZIF_32: J1.32, J2.22
/ZIF_33: J1.33, J2.23, Q6.3 (C)
/ZIF_34: J1.34, J2.24, Q5.3 (C)
/ZIF_35: J1.35, J2.25, Q4.3 (C)
/ZIF_36: J1.36, J2.26, Q3.3 (C)
/ZIF_37: J1.37, J2.27
/ZIF_38: J1.38, J2.28, Q2.3 (C)
/ZIF_39: J1.39, J2.29
/ZIF_40: J1.40, J2.30, Q1.3 (C)
/ZIF_41: J1.41, J2.31
/~PWR_0: R1.1, U2.15 (O0)
/~PWR_1: R2.1, U2.14 (O1)
/~PWR_2: R3.1, U2.13 (O2)
/~PWR_3: R4.1, U2.12 (O3)
/~PWR_4: R5.1, U2.11 (O4)
/~PWR_5: R6.1, U2.10 (O5)
/~PWR_6: R7.1, U2.9 (O6)
GND: C1.2, C2.2, J1.21, J2.16, U2.4 (E1), U2.5 (E2), U2.8 (GND)
unnamed: Q1.1 (B), R1.2
unnamed: Q2.1 (B), R2.2
unnamed: Q3.1 (B), R3.2
unnamed: Q4.1 (B), R4.2
unnamed: Q5.1 (B), R5.2
unnamed: Q6.1 (B), R6.2
unnamed: Q7.1 (B), R7.2
VCC: C1.1, C2.1, J1.42, J2.32, Q1.2 (E), Q2.2 (E), Q3.2 (E), Q4.2 (E), Q5.2 (E), Q6.2 (E), Q7.2 (E), U2.6 (E3), U2.16 (VCC)

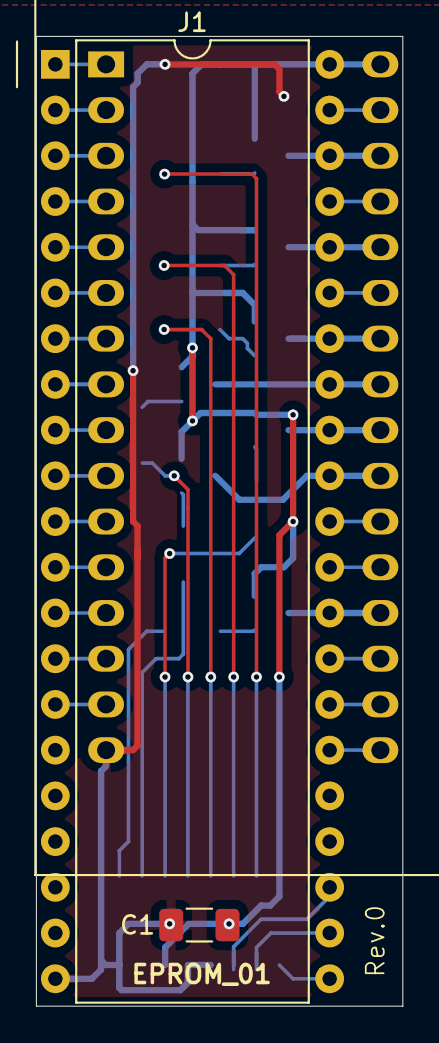
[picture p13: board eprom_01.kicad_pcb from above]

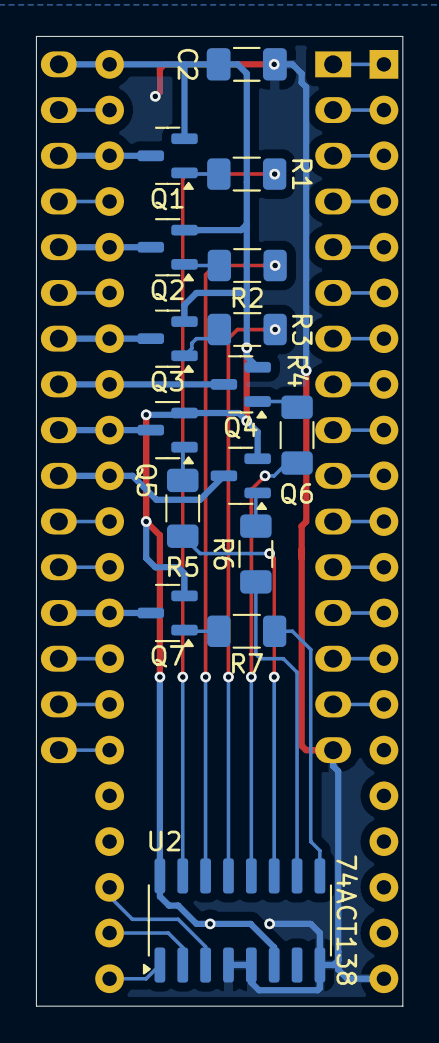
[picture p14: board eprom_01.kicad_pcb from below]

Board: 2 copper layers, 20.4 x 53.9 mm, 19 parts (16 on the bottom side), 49 nets.

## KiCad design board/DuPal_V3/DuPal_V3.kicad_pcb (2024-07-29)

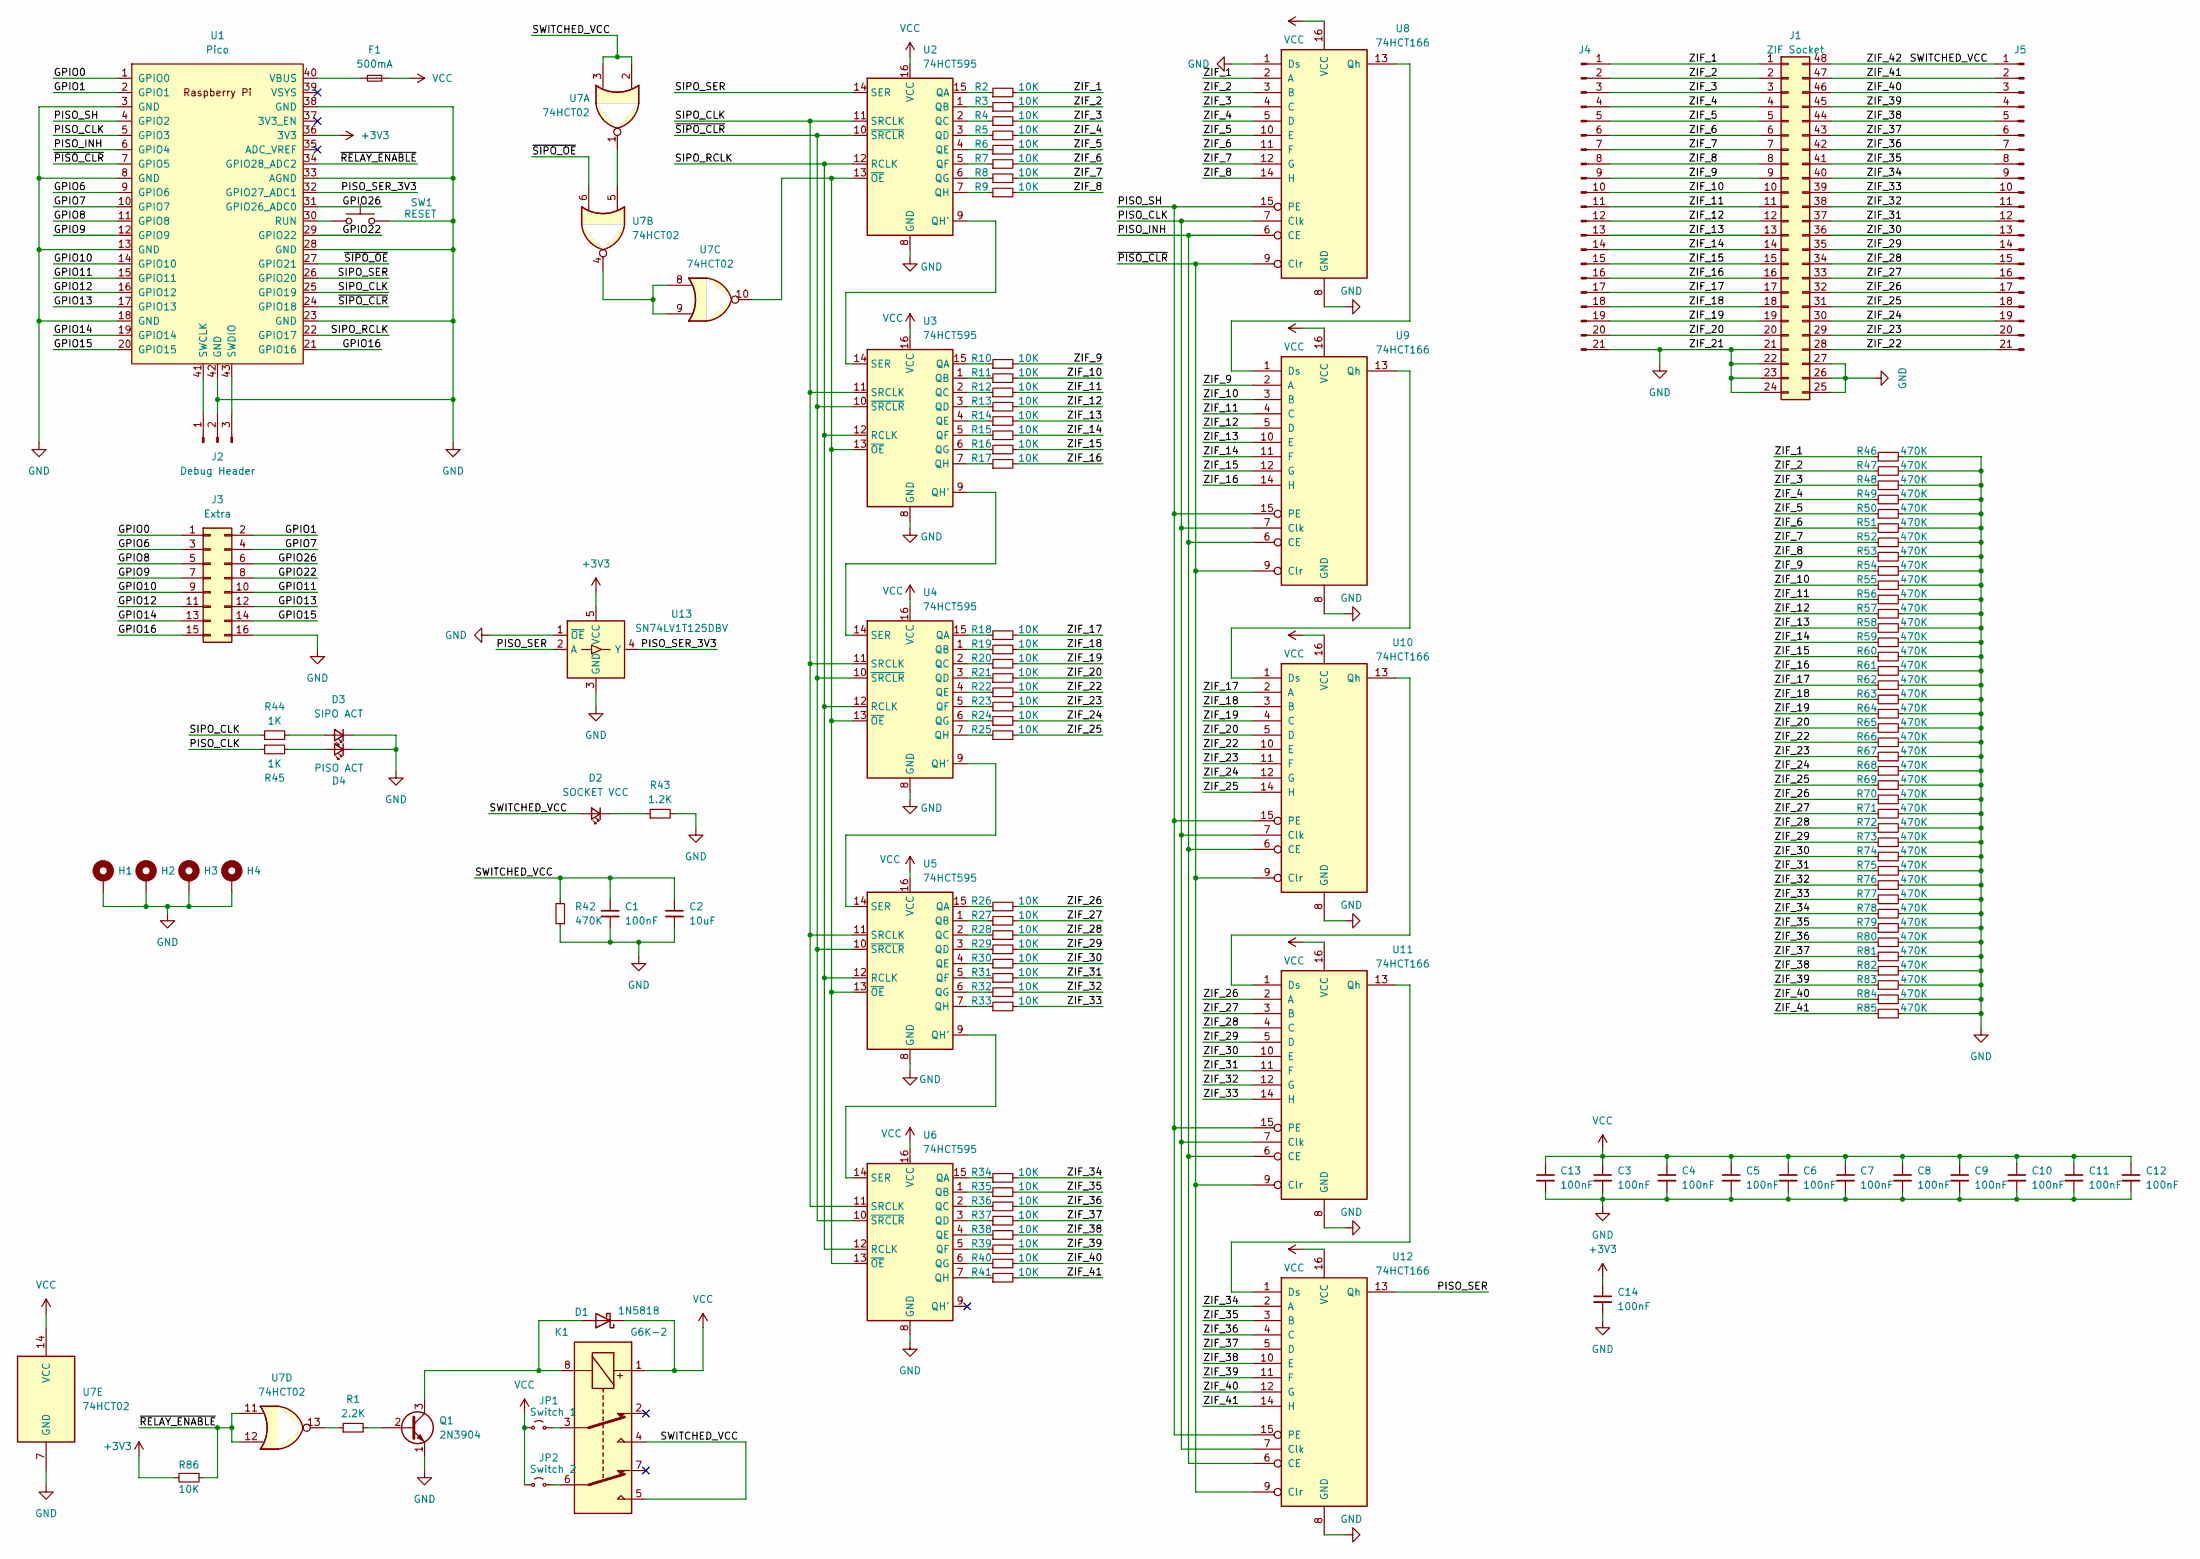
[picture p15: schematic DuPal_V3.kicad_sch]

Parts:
C1, C3, C4, C5, C6, C7, C8, C9, C10, C11, C12, C13, C14: 100nF; C_1206_3216Metric_Pad1.33x1.80mm_HandSolder
C2: 10uF; C_1206_3216Metric_Pad1.33x1.80mm_HandSolder
D1: 1N5818; D_DO-41_SOD81_P10.16mm_Horizontal
D2: SOCKET VCC; LED_1206_3216Metric_Pad1.42x1.75mm_HandSolder
D3: SIPO ACT; LED_1206_3216Metric_Pad1.42x1.75mm_HandSolder
D4: PISO ACT; LED_1206_3216Metric_Pad1.42x1.75mm_HandSolder
F1: 500mA; Fuse_1206_3216Metric_Pad1.42x1.75mm_HandSolder
H1, H2, H3, H4: MountingHole_Pad; MountingHole_3.2mm_M3_DIN965_Pad
J1: ZIF Socket; DIP_Socket-48
J2: Debug Header; PinHeader_1x03_P2.54mm_Vertical
J3: Extra; PinHeader_2x08_P2.54mm_Vertical
J4, J5: Conn_01x21_Pin; PinHeader_1x21_P2.54mm_Vertical
JP1: Switch 1; SolderJumper-2_P1.3mm_Bridged_RoundedPad1.0x1.5mm
JP2: Switch 2; SolderJumper-2_P1.3mm_Open_RoundedPad1.0x1.5mm
K1: G6K-2; Relay_DPDT_Omron_G6K-2P-Y
Q1: 2N3904; TO-92_Inline
R1: 2.2K; R_1206_3216Metric_Pad1.30x1.75mm_HandSolder
R2, R3, R4, R5, R6, R7, R8, R9, R10, R11, R12, R13, R14, R15, R16, R17, R18, R19, R20, R21, R22, R23, R24, R25, R26, R27, R28, R29, R30, R31, R32, R33, R34, R35, R36, R37, R38, R39, R40, R41, R86: 10K; R_1206_3216Metric_Pad1.30x1.75mm_HandSolder
R42, R46, R47, R48, R49, R50, R51, R52, R53, R54, R55, R56, R57, R58, R59, R60, R61, R62, R63, R64, R65, R66, R67, R68, R69, R70, R71, R72, R73, R74, R75, R76, R77, R78, R79, R80, R81, R82, R83, R84, R85: 470K; R_1206_3216Metric_Pad1.30x1.75mm_HandSolder
R43: 1.2K; R_1206_3216Metric_Pad1.30x1.75mm_HandSolder
R44, R45: 1K; R_1206_3216Metric_Pad1.30x1.75mm_HandSolder
SW1: RESET; SW_PUSH_6mm
U1: Pico; RPi_Pico_SMD_TH
U2, U3, U4, U5, U6: 74HCT595; SOIC-16_3.9x9.9mm_P1.27mm
U7: 74HCT02; SOIC-14_3.9x8.7mm_P1.27mm
U8, U9, U10, U11, U12: 74HCT166; SOIC-16_3.9x9.9mm_P1.27mm
U13: SN74LV1T125DBV; SOT-23-5

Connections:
+3V3: C14.1, R86.2, U1.36 (3V3), U13.5 (VCC)
/GPIO0: J3.1, U1.1 (GPIO0)
/GPIO1: J3.2, U1.2 (GPIO1)
/GPIO6: J3.3, U1.9 (GPIO6)
/GPIO7: J3.4, U1.10 (GPIO7)
/GPIO8: J3.5, U1.11 (GPIO8)
/GPIO9: J3.7, U1.12 (GPIO9)
/GPIO10: J3.9, U1.14 (GPIO10)
/GPIO11: J3.10, U1.15 (GPIO11)
/GPIO12: J3.11, U1.16 (GPIO12)
/GPIO13: J3.12, U1.17 (GPIO13)
/GPIO14: J3.13, U1.19 (GPIO14)
/GPIO15: J3.14, U1.20 (GPIO15)
/GPIO16: J3.15, U1.21 (GPIO16)
/GPIO22: J3.8, U1.29 (GPIO22)
/GPIO26: J3.6, U1.31 (GPIO26_ADC0)
/PISO_CLK: R45.1, U1.5 (GPIO3), U8.7 (Clk), U9.7 (Clk), U10.7 (Clk), U11.7 (Clk), U12.7 (Clk)
/PISO_INH: U1.6 (GPIO4), U8.6 (CE), U9.6 (CE), U10.6 (CE), U11.6 (CE), U12.6 (CE)
/PISO_SER: U12.13 (Qh), U13.2 (A)
/PISO_SER_3V3: U1.32 (GPIO27_ADC1), U13.4 (Y)
/PISO_SH: U1.4 (GPIO2), U8.15 (PE), U9.15 (PE), U10.15 (PE), U11.15 (PE), U12.15 (PE)
/SIPO_CLK: R44.1, U1.25 (GPIO19), U2.11 (SRCLK), U3.11 (SRCLK), U4.11 (SRCLK), U5.11 (SRCLK), U6.11 (SRCLK)
/SIPO_RCLK: U1.22 (GPIO17), U2.12 (RCLK), U3.12 (RCLK), U4.12 (RCLK), U5.12 (RCLK), U6.12 (RCLK)
/SIPO_SER: U1.26 (GPIO20), U2.14 (SER)
/SWITCHED_VCC: C1.1, C2.1, D2.2 (A), J1.48, J5.1, K1.4, K1.5, R42.2, U7.2, U7.3
/ZIF_1: J1.1, J4.1, R2.2, R46.1, U8.2 (A)
/ZIF_2: J1.2, J4.2, R3.2, R47.1, U8.3 (B)
/ZIF_3: J1.3, J4.3, R4.2, R48.1, U8.4 (C)
/ZIF_4: J1.4, J4.4, R5.2, R49.1, U8.5 (D)
/ZIF_5: J1.5, J4.5, R6.2, R50.1, U8.10 (E)
/ZIF_6: J1.6, J4.6, R7.2, R51.1, U8.11 (F)
/ZIF_7: J1.7, J4.7, R8.2, R52.1, U8.12 (G)
/ZIF_8: J1.8, J4.8, R9.2, R53.1, U8.14 (H)
/ZIF_9: J1.9, J4.9, R10.2, R54.1, U9.2 (A)
/ZIF_10: J1.10, J4.10, R11.2, R55.1, U9.3 (B)
/ZIF_11: J1.11, J4.11, R12.2, R56.1, U9.4 (C)
/ZIF_12: J1.12, J4.12, R13.2, R57.1, U9.5 (D)
/ZIF_13: J1.13, J4.13, R14.2, R58.1, U9.10 (E)
/ZIF_14: J1.14, J4.14, R15.2, R59.1, U9.11 (F)
/ZIF_15: J1.15, J4.15, R16.2, R60.1, U9.12 (G)
/ZIF_16: J1.16, J4.16, R17.2, R61.1, U9.14 (H)
/ZIF_17: J1.17, J4.17, R18.2, R62.1, U10.2 (A)
/ZIF_18: J1.18, J4.18, R19.2, R63.1, U10.3 (B)
/ZIF_19: J1.19, J4.19, R20.2, R64.1, U10.4 (C)
/ZIF_20: J1.20, J4.20, R21.2, R65.1, U10.5 (D)
/ZIF_22: J1.28, J5.21, R22.2, R66.1, U10.10 (E)
/ZIF_23: J1.29, J5.20, R23.2, R67.1, U10.11 (F)
/ZIF_24: J1.30, J5.19, R24.2, R68.1, U10.12 (G)
/ZIF_25: J1.31, J5.18, R25.2, R69.1, U10.14 (H)
/ZIF_26: J1.32, J5.17, R26.2, R70.1, U11.2 (A)
/ZIF_27: J1.33, J5.16, R27.2, R71.1, U11.3 (B)
/ZIF_28: J1.34, J5.15, R28.2, R72.1, U11.4 (C)
/ZIF_29: J1.35, J5.14, R29.2, R73.1, U11.5 (D)
/ZIF_30: J1.36, J5.13, R30.2, R74.1, U11.10 (E)
/ZIF_31: J1.37, J5.12, R31.2, R75.1, U11.11 (F)
/ZIF_32: J1.38, J5.11, R32.2, R76.1, U11.12 (G)
/ZIF_33: J1.39, J5.10, R33.2, R77.1, U11.14 (H)
/ZIF_34: J1.40, J5.9, R34.2, R78.1, U12.2 (A)
/ZIF_35: J1.41, J5.8, R35.2, R79.1, U12.3 (B)
/ZIF_36: J1.42, J5.7, R36.2, R80.1, U12.4 (C)
/ZIF_37: J1.43, J5.6, R37.2, R81.1, U12.5 (D)
/ZIF_38: J1.44, J5.5, R38.2, R82.1, U12.10 (E)
/ZIF_39: J1.45, J5.4, R39.2, R83.1, U12.11 (F)
/ZIF_40: J1.46, J5.3, R40.2, R84.1, U12.12 (G)
/ZIF_41: J1.47, J5.2, R41.2, R85.1, U12.14 (H)
/~PISO_CLR: U1.7 (GPIO5), U8.9 (Clr), U9.9 (Clr), U10.9 (Clr), U11.9 (Clr), U12.9 (Clr)
/~RELAY_ENABLE: R86.1, U1.34 (GPIO28_ADC2), U7.11, U7.12
/~SIPO_CLR: U1.24 (GPIO18), U2.10 (~SRCLR), U3.10 (~SRCLR), U4.10 (~SRCLR), U5.10 (~SRCLR), U6.10 (~SRCLR)
/~SIPO_OE: U1.27 (GPIO21), U7.6
GND: C1.2, C2.2, C3.2, C4.2, C5.2, C6.2, C7.2, C8.2, C9.2, C10.2, C11.2, C12.2, C13.2, C14.2, D3.1 (K), D4.1 (K), H1.1, H2.1, H3.1, H4.1, J1.21, J1.22, J1.23, J1.24, J1.25, J1.26, J1.27, J2.2, J3.16, J4.21, Q1.1 (E), R42.1, R43.2, R46.2, R47.2, R48.2, R49.2, R50.2, R51.2, R52.2, R53.2, R54.2, R55.2, R56.2, R57.2, R58.2, R59.2, R60.2, R61.2, R62.2, R63.2, R64.2, R65.2, R66.2, R67.2, R68.2, R69.2, R70.2, R71.2, R72.2, R73.2, R74.2, R75.2, R76.2, R77.2, R78.2, R79.2, R80.2, R81.2, R82.2, R83.2, R84.2, R85.2, SW1.2, U1.3 (GND), U1.8 (GND), U1.13 (GND), U1.18 (GND), U1.23 (GND), U1.28 (GND), U1.33 (AGND), U1.38 (GND), U1.42 (GND), U2.8 (GND), U3.8 (GND), U4.8 (GND), U5.8 (GND), U6.8 (GND), U7.7 (GND), U8.1 (Ds), U8.8 (GND), U9.8 (GND), U10.8 (GND), U11.8 (GND), U12.8 (GND), U13.1 (~OE), U13.3 (GND)
unnamed: D1.2 (A), K1.8, Q1.3 (C)
unnamed: D2.1 (K), R43.1
unnamed: D3.2 (A), R44.2
unnamed: D4.2 (A), R45.2
unnamed: J2.1, U1.41 (SWCLK)
unnamed: J2.3, U1.43 (SWDIO)
unnamed: JP1.2 (B), K1.3
unnamed: JP2.2 (B), K1.6
unnamed: Q1.2 (B), R1.2
unnamed: R1.1, U7.13
unnamed: SW1.1, U1.30 (RUN)
unnamed: F1.1, U1.40 (VBUS)
unnamed: R2.1, U2.15 (QA)
unnamed: R3.1, U2.1 (QB)
unnamed: R4.1, U2.2 (QC)
unnamed: R5.1, U2.3 (QD)
unnamed: R6.1, U2.4 (QE)
unnamed: R7.1, U2.5 (QF)
unnamed: R8.1, U2.6 (QG)
unnamed: U2.9 (QH'), U3.14 (SER)
unnamed: R9.1, U2.7 (QH)
unnamed: U2.13 (~OE), U3.13 (~OE), U4.13 (~OE), U5.13 (~OE), U6.13 (~OE), U7.10
unnamed: R10.1, U3.15 (QA)
unnamed: R11.1, U3.1 (QB)
unnamed: R12.1, U3.2 (QC)
unnamed: R13.1, U3.3 (QD)
unnamed: R14.1, U3.4 (QE)
unnamed: R15.1, U3.5 (QF)
unnamed: R16.1, U3.6 (QG)
unnamed: U3.9 (QH'), U4.14 (SER)
unnamed: R17.1, U3.7 (QH)
unnamed: R18.1, U4.15 (QA)
unnamed: R19.1, U4.1 (QB)
unnamed: R20.1, U4.2 (QC)
unnamed: R21.1, U4.3 (QD)
unnamed: R22.1, U4.4 (QE)
unnamed: R23.1, U4.5 (QF)
unnamed: R24.1, U4.6 (QG)
unnamed: U4.9 (QH'), U5.14 (SER)
unnamed: R25.1, U4.7 (QH)
unnamed: R26.1, U5.15 (QA)
unnamed: R27.1, U5.1 (QB)
unnamed: R28.1, U5.2 (QC)
unnamed: R29.1, U5.3 (QD)
unnamed: R30.1, U5.4 (QE)
unnamed: R31.1, U5.5 (QF)
unnamed: R32.1, U5.6 (QG)
unnamed: U5.9 (QH'), U6.14 (SER)
unnamed: R33.1, U5.7 (QH)
unnamed: R34.1, U6.15 (QA)
unnamed: R35.1, U6.1 (QB)
unnamed: R36.1, U6.2 (QC)
unnamed: R37.1, U6.3 (QD)
unnamed: R38.1, U6.4 (QE)
unnamed: R39.1, U6.5 (QF)
unnamed: R40.1, U6.6 (QG)
unnamed: R41.1, U6.7 (QH)
unnamed: U7.1, U7.5
unnamed: U7.4, U7.8, U7.9
unnamed: U8.13 (Qh), U9.1 (Ds)
unnamed: U9.13 (Qh), U10.1 (Ds)
unnamed: U10.13 (Qh), U11.1 (Ds)
unnamed: U11.13 (Qh), U12.1 (Ds)
VCC: C3.1, C4.1, C5.1, C6.1, C7.1, C8.1, C9.1, C10.1, C11.1, C12.1, C13.1, D1.1 (K), F1.2, JP1.1 (A), JP2.1 (A), K1.1, U2.16 (VCC), U3.16 (VCC), U4.16 (VCC), U5.16 (VCC), U6.16 (VCC), U7.14 (VCC), U8.16 (VCC), U9.16 (VCC), U10.16 (VCC), U11.16 (VCC), U12.16 (VCC)

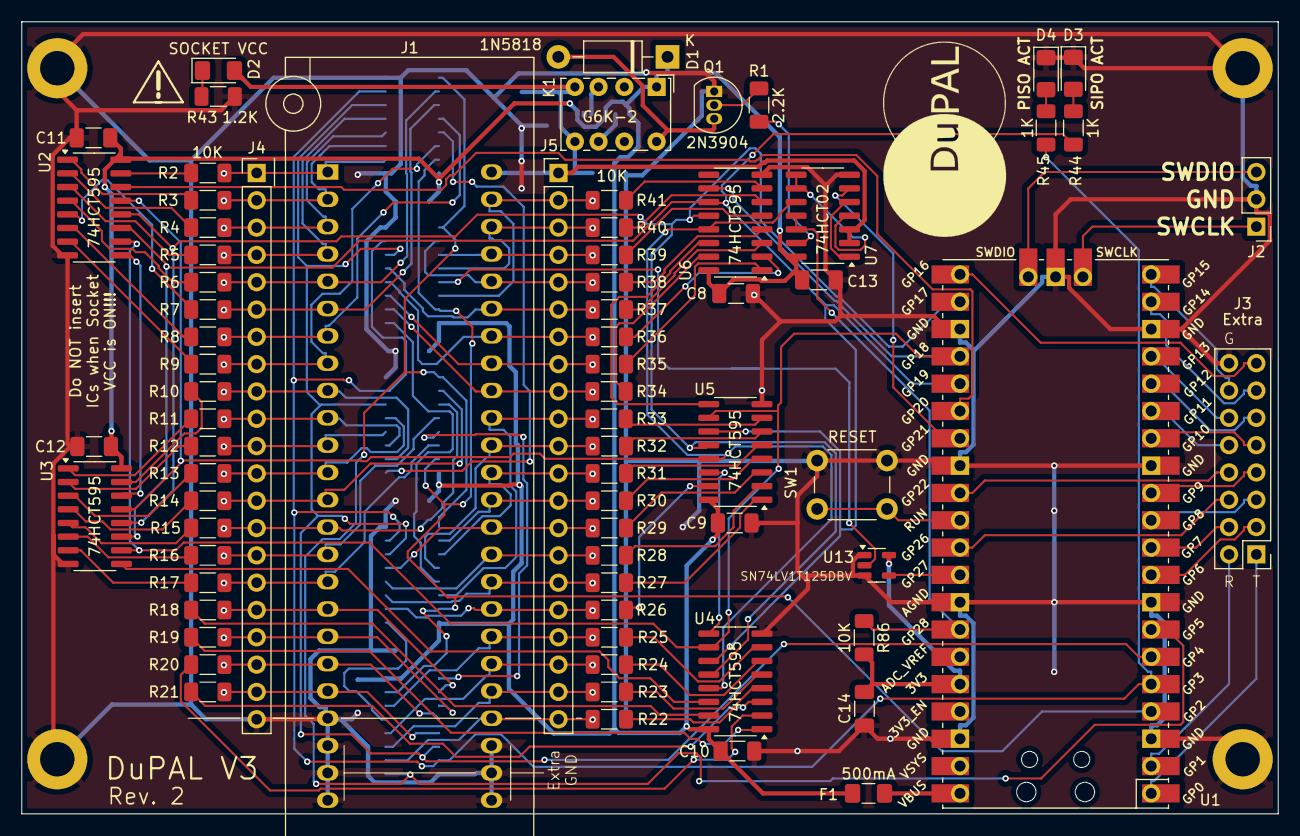
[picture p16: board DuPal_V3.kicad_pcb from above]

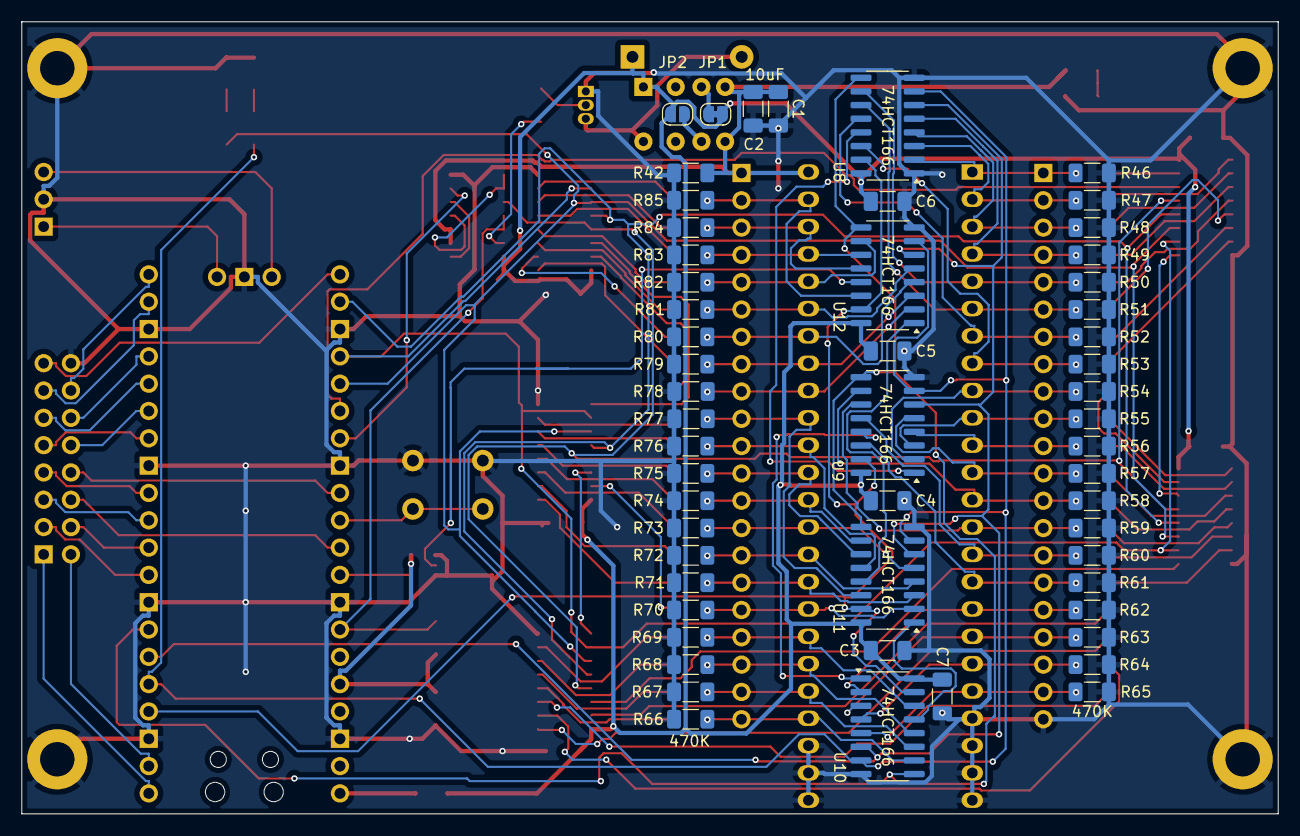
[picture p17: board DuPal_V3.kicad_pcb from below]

Board: 2 copper layers, 116.8 x 73.7 mm, 132 parts (55 on the bottom side), 134 nets.

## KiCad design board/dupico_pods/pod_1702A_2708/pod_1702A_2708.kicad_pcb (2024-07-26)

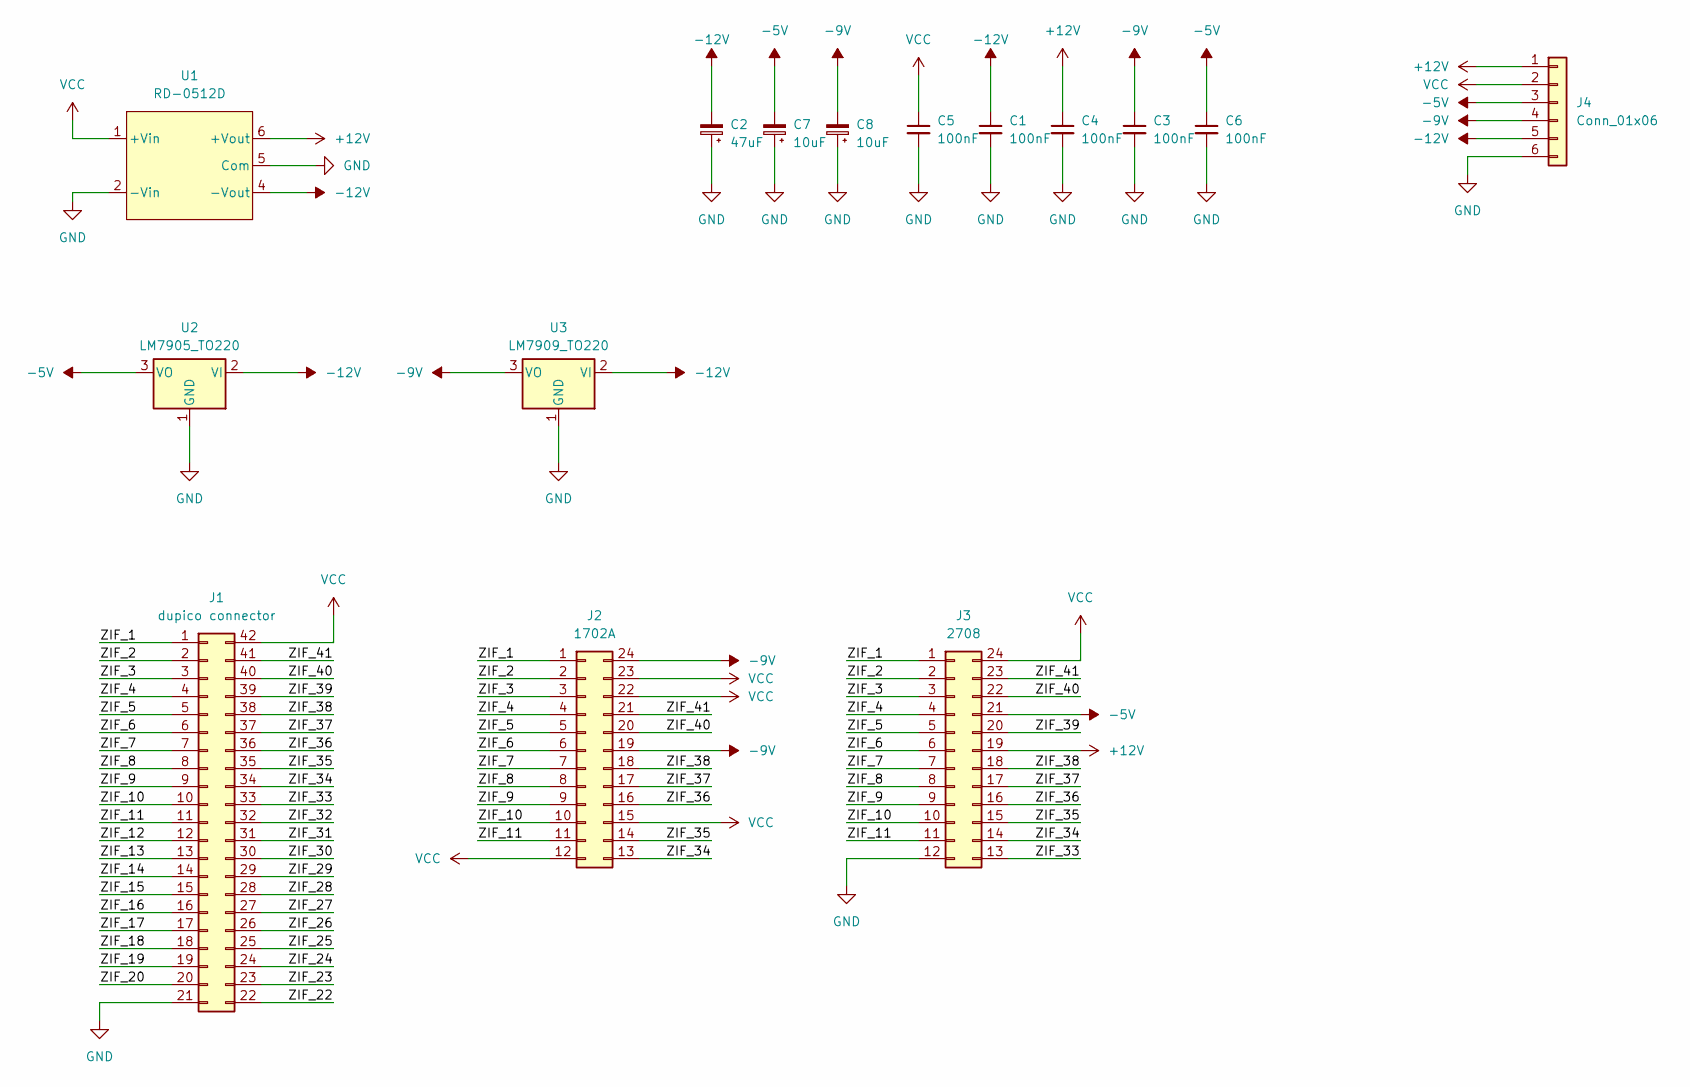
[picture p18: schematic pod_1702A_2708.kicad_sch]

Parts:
C1, C3, C4, C5, C6: 100nF; C_1206_3216Metric_Pad1.33x1.80mm_HandSolder
C2: 47uF; CP_Radial_D5.0mm_P2.00mm
C7, C8: 10uF; CP_Radial_D5.0mm_P2.00mm
J1: dupico connector; DIP-42_W15.24mm
J2: 1702A; DIP_Socket-24_W11.9_W12.7_W15.24_W17.78_W18.5_3M_224-1275-0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
J3: 2708; DIP_Socket-24_W11.9_W12.7_W15.24_W17.78_W18.5_3M_224-1275-0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
J4: Conn_01x06; PinHeader_1x06_P2.54mm_Vertical
U1: RD-0512D; Recom_SIP6
U2: LM7905_TO220; TO-220-3_Vertical
U3: LM7909_TO220; TO-220-3_Vertical

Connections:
+12V: C4.1, J3.19, J4.1, U1.6 (+Vout)
-5V: C6.1, C7.2, J3.21, J4.3, U2.3 (VO)
-9V: C3.1, C8.2, J2.19, J2.24, J4.4, U3.3 (VO)
-12V: C1.1, C2.2, J4.5, U1.4 (-Vout), U2.2 (VI), U3.2 (VI)
/ZIF_1: J1.1, J2.1, J3.1
/ZIF_2: J1.2, J2.2, J3.2
/ZIF_3: J1.3, J2.3, J3.3
/ZIF_4: J1.4, J2.4, J3.4
/ZIF_5: J1.5, J2.5, J3.5
/ZIF_6: J1.6, J2.6, J3.6
/ZIF_7: J1.7, J2.7, J3.7
/ZIF_8: J1.8, J2.8, J3.8
/ZIF_9: J1.9, J2.9, J3.9
/ZIF_10: J1.10, J2.10, J3.10
/ZIF_11: J1.11, J2.11, J3.11
/ZIF_12: J1.12
/ZIF_13: J1.13
/ZIF_14: J1.14
/ZIF_15: J1.15
/ZIF_16: J1.16
/ZIF_17: J1.17
/ZIF_18: J1.18
/ZIF_19: J1.19
/ZIF_20: J1.20
/ZIF_22: J1.22
/ZIF_23: J1.23
/ZIF_24: J1.24
/ZIF_25: J1.25
/ZIF_26: J1.26
/ZIF_27: J1.27
/ZIF_28: J1.28
/ZIF_29: J1.29
/ZIF_30: J1.30
/ZIF_31: J1.31
/ZIF_32: J1.32
/ZIF_33: J1.33, J3.13
/ZIF_34: J1.34, J2.13, J3.14
/ZIF_35: J1.35, J2.14, J3.15
/ZIF_36: J1.36, J2.16, J3.16
/ZIF_37: J1.37, J2.17, J3.17
/ZIF_38: J1.38, J2.18, J3.18
/ZIF_39: J1.39, J3.20
/ZIF_40: J1.40, J2.20, J3.22
/ZIF_41: J1.41, J2.21, J3.23
GND: C1.2, C2.1, C3.2, C4.2, C5.2, C6.2, C7.1, C8.1, J1.21, J3.12, J4.6, U1.2 (-Vin), U1.5 (Com), U2.1 (GND), U3.1 (GND)
VCC: C5.1, J1.42, J2.12, J2.15, J2.22, J2.23, J3.24, J4.2, U1.1 (+Vin)

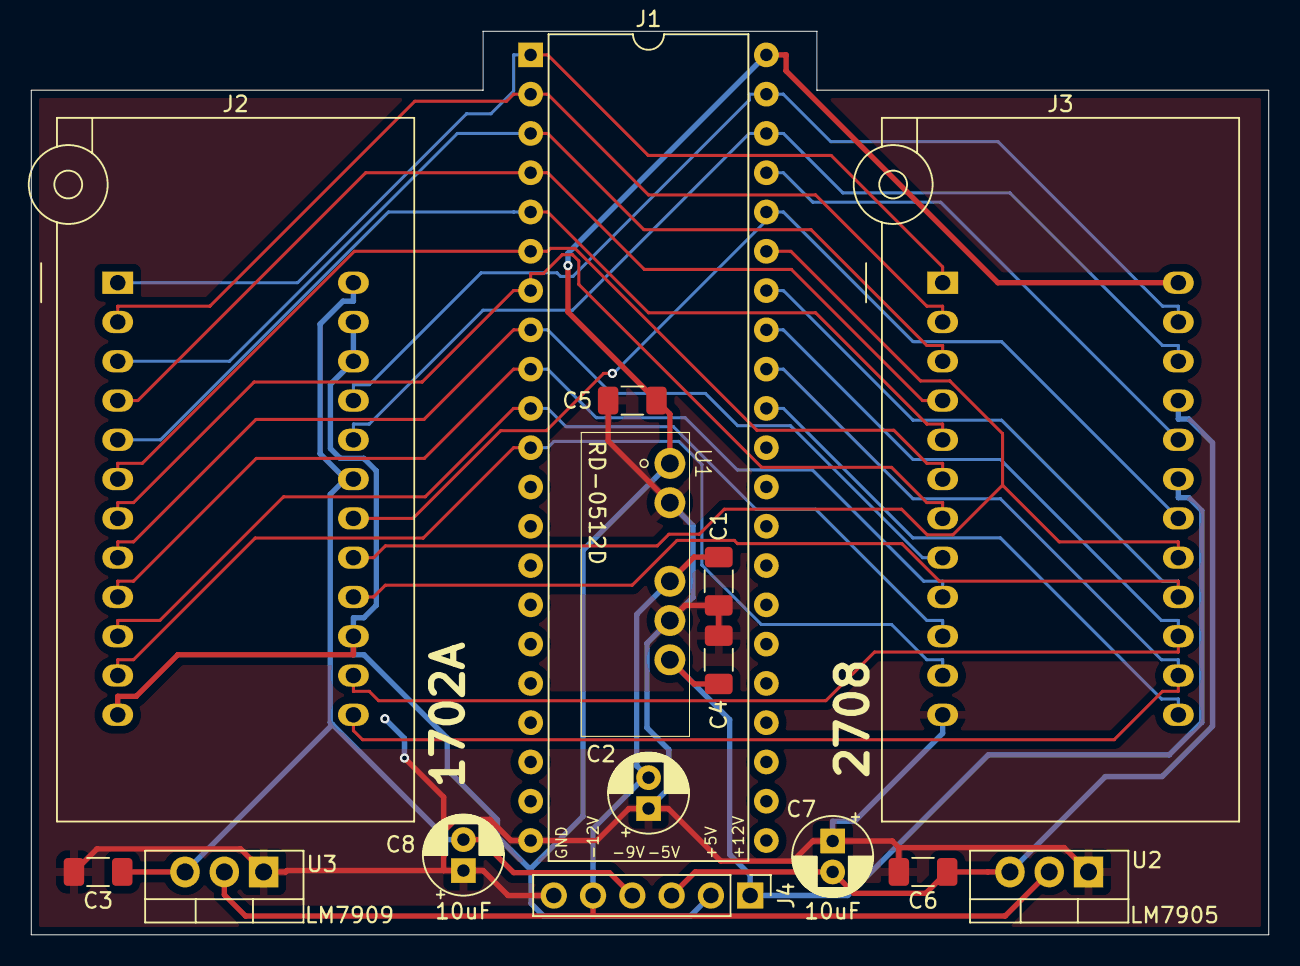
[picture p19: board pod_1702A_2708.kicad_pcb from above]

Board: 2 copper layers, 80.0 x 58.4 mm, 15 parts (0 on the bottom side), 26 nets.

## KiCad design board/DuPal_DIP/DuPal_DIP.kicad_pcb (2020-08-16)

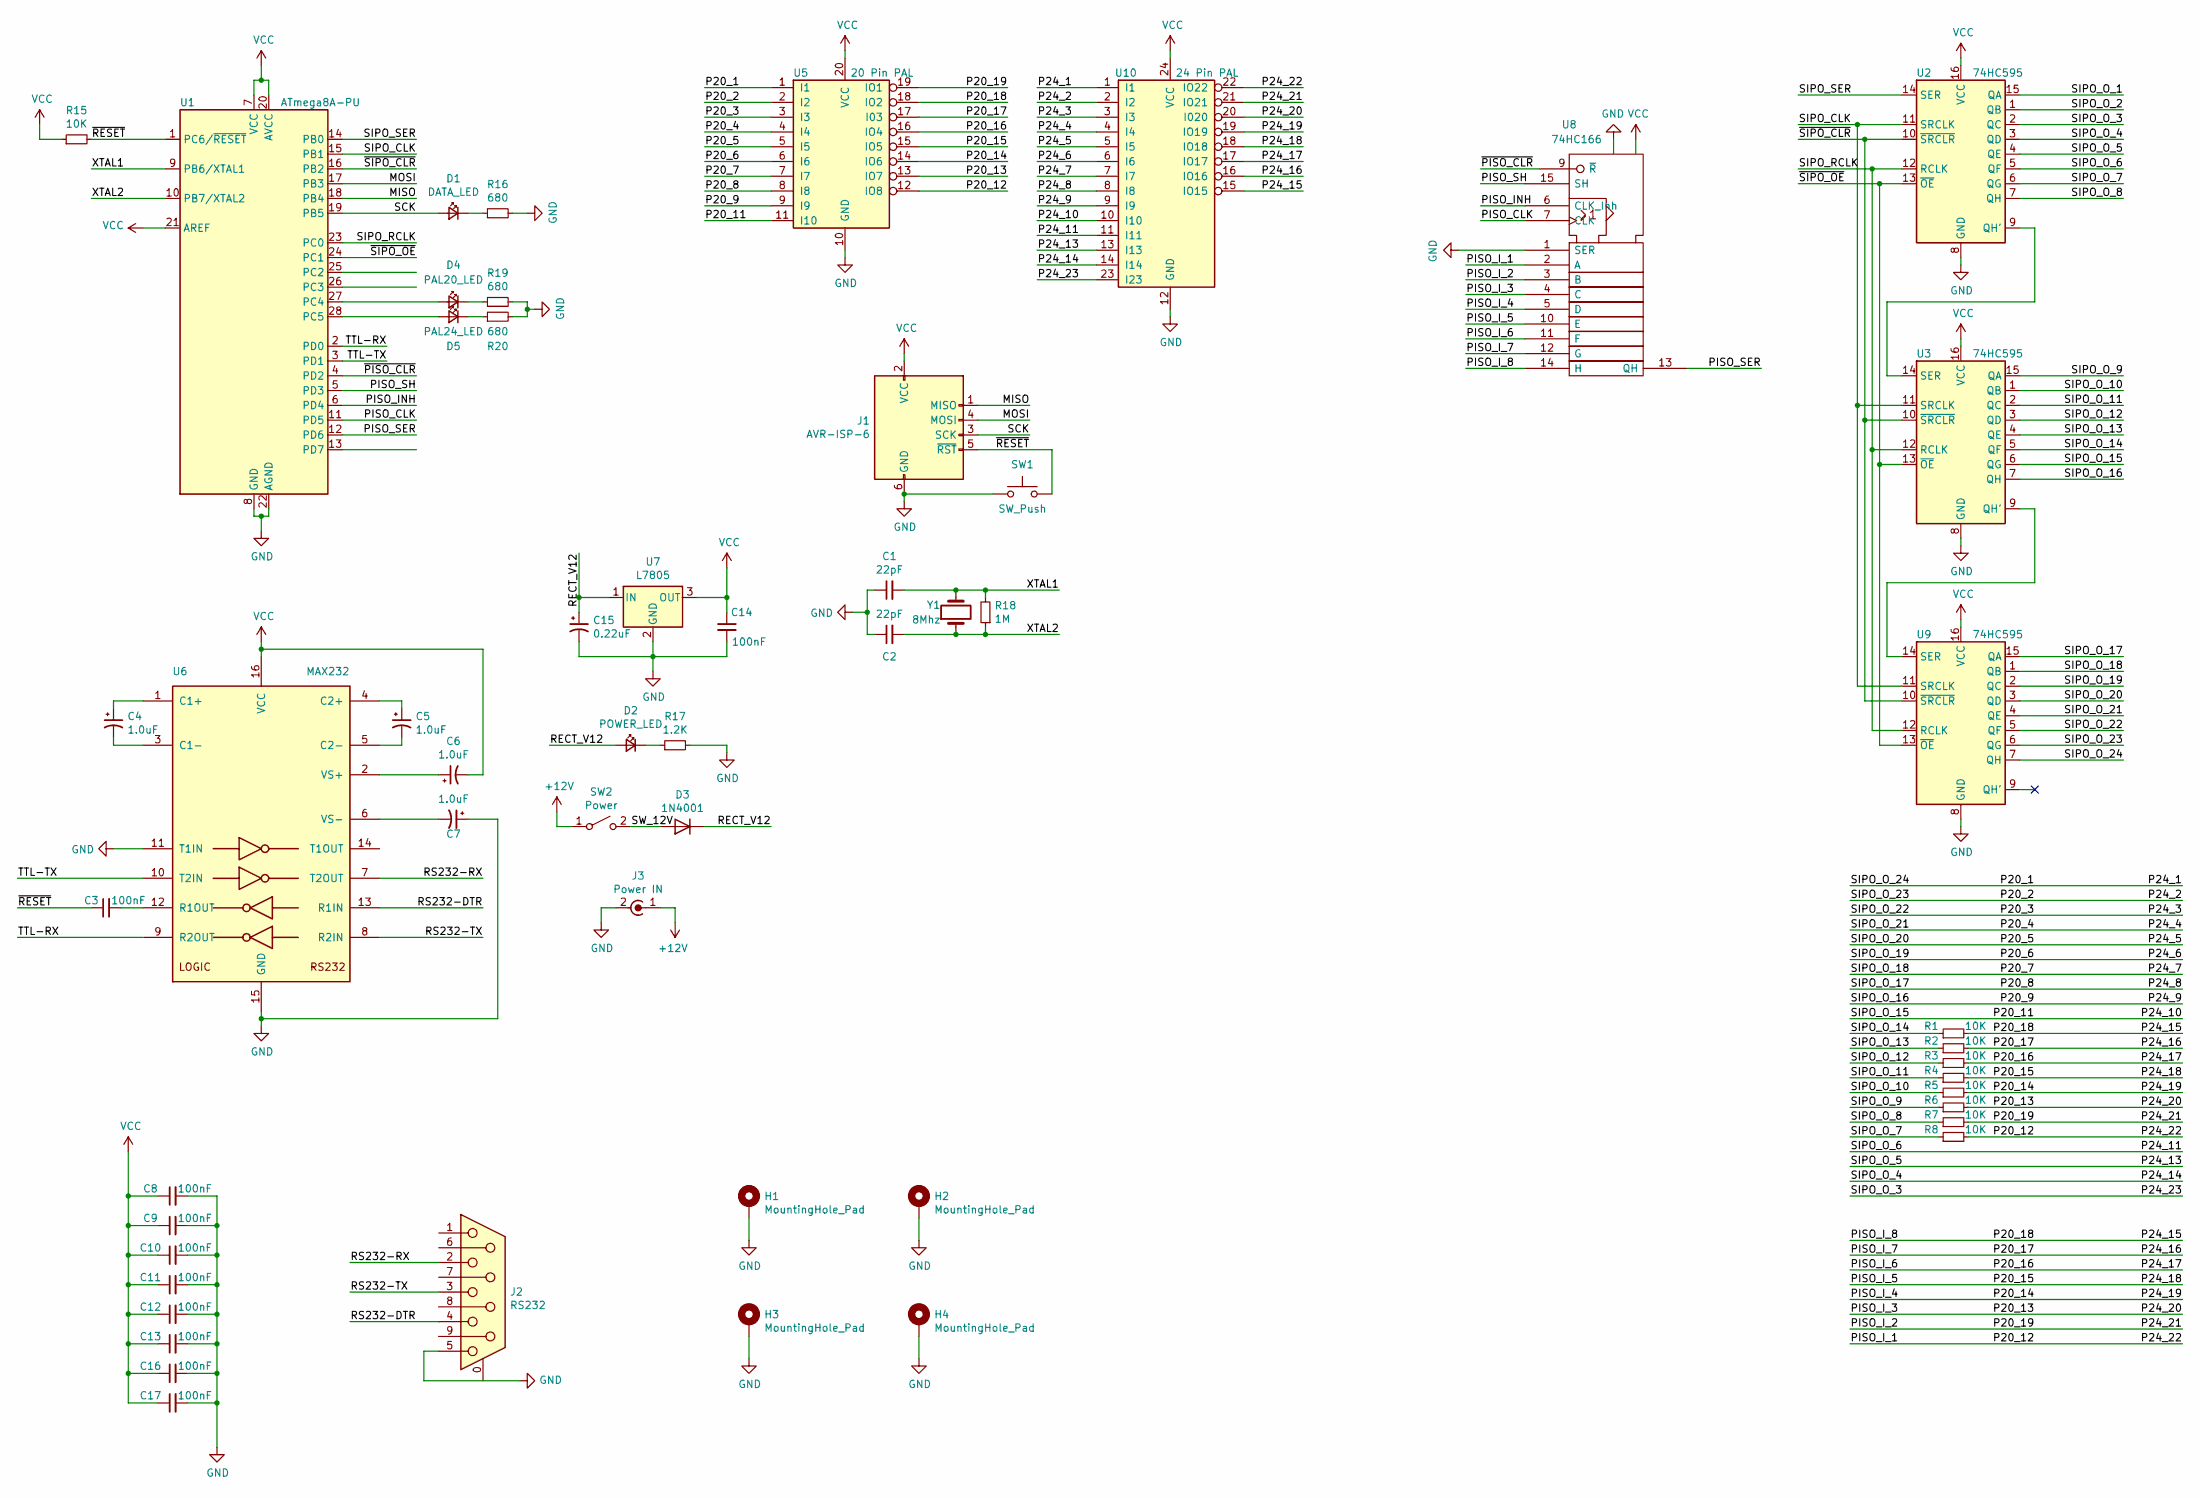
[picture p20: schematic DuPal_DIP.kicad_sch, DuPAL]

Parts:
C1, C2: 22pF; C_Disc_D3.0mm_W2.0mm_P2.50mm
C3, C8, C9, C10, C11, C12, C13, C14, C16, C17: 100nF; C_Disc_D3.4mm_W2.1mm_P2.50mm
C4, C5, C6, C7: 1.0uF; CP_Radial_D5.0mm_P2.50mm
C15: 0.22uF; CP_Radial_D5.0mm_P2.50mm
D1: DATA_LED; LED_D2.0mm_W4.8mm_H2.5mm_FlatTop
D2: POWER_LED; LED_D2.0mm_W4.8mm_H2.5mm_FlatTop
D3: 1N4001; D_DO-41_SOD81_P10.16mm_Horizontal
D4: PAL20_LED; LED_D2.0mm_W4.8mm_H2.5mm_FlatTop
D5: PAL24_LED; LED_D2.0mm_W4.8mm_H2.5mm_FlatTop
H1, H2, H3, H4: MountingHole_Pad; MountingHole_2.7mm_M2.5_ISO7380_Pad
J1: AVR-ISP-6; IDC-Header_2x03_P2.54mm_Vertical
J2: RS232; DSUB-9_Female_Horizontal_P2.77x2.84mm_EdgePinOffset4.94mm_H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
J3: Power IN; BarrelJack_Horizontal
R1, R2, R3, R4, R5, R6, R7, R8, R15: 10K; R_Axial_DIN0204_L3.6mm_D1.6mm_P7.62mm_Horizontal
R16, R19, R20: 680; R_Axial_DIN0204_L3.6mm_D1.6mm_P7.62mm_Horizontal
R17: 1.2K; R_Axial_DIN0204_L3.6mm_D1.6mm_P7.62mm_Horizontal
R18: 1M; R_Axial_DIN0204_L3.6mm_D1.6mm_P7.62mm_Horizontal
SW1: SW_Push; SW_PUSH_6mm
SW2: Power; SW_Slide_1P2T_CK_OS102011MS2Q
U1: ATmega8A-PU; DIP-28_W7.62mm
U2, U3, U9: 74HC595; DIP-16_W7.62mm
U5: 20 Pin PAL; DIP_Socket-20_W4.3_W5.08_W7.62_W10.16_W10.9_3M_220-3342-00-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
U6: MAX232; DIP-16_W7.62mm
U7: L7805; TO-220-3_Horizontal_TabDown
U8: 74HC166; DIP-16_W7.62mm
U10: 24 Pin PAL; DIP_Socket-24_W4.3_W5.08_W7.62_W10.16_W10.9_3M_224-5248-00-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
Y1: 8Mhz; Crystal_HC49-U_Vertical

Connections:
+12V: J3.1 (In), SW2.1 (A)
/MISO: J1.1 (MISO), U1.18 (PB4)
/MOSI: J1.4 (MOSI), U1.17 (PB3)
/P20_1: U5.1 (I1), U9.7 (QH), U10.1 (I1)
/P20_2: U5.2 (I2), U9.6 (QG), U10.2 (I2)
/P20_3: U5.3 (I3), U9.5 (QF), U10.3 (I3)
/P20_4: U5.4 (I4), U9.4 (QE), U10.4 (I4)
/P20_5: U5.5 (I5), U9.3 (QD), U10.5 (I5)
/P20_6: U5.6 (I6), U9.2 (QC), U10.6 (I6)
/P20_7: U5.7 (I7), U9.1 (QB), U10.7 (I7)
/P20_8: U5.8 (I8), U9.15 (QA), U10.8 (I8)
/P20_9: U3.7 (QH), U5.9 (I9), U10.9 (I9)
/P20_11: U3.6 (QG), U5.11 (I10), U10.10 (I10)
/P20_12: R8.2, U5.12 (IO8), U8.2 (A), U10.22 (IO22)
/P20_13: R6.2, U5.13 (IO7), U8.4 (C), U10.20 (I020)
/P20_14: R5.2, U5.14 (IO6), U8.5 (D), U10.19 (IO19)
/P20_15: R4.2, U5.15 (IO5), U8.10 (E), U10.18 (IO18)
/P20_16: R3.2, U5.16 (IO4), U8.11 (F), U10.17 (IO17)
/P20_17: R2.2, U5.17 (I03), U8.12 (G), U10.16 (IO16)
/P20_18: R1.2, U5.18 (IO2), U8.14 (H), U10.15 (IO15)
/P20_19: R7.2, U5.19 (IO1), U8.3 (B), U10.21 (IO21)
/P24_11: U2.5 (QF), U10.11 (I11)
/P24_13: U2.4 (QE), U10.13 (I13)
/P24_14: U2.3 (QD), U10.14 (I14)
/P24_23: U2.2 (QC), U10.23 (I23)
/PISO_CLK: U1.11 (PD5), U8.7 (CLK)
/PISO_INH: U1.6 (PD4), U8.6 (CLK_Inh)
/PISO_SER: U1.12 (PD6), U8.13 (QH)
/PISO_SH: U1.5 (PD3), U8.15 (SH)
/RECT_V12: C15.1, D2.2 (A), D3.1 (K), U7.1 (IN)
/RS232-DTR: J2.4, U6.13 (R1IN)
/RS232-RX: J2.2, U6.7 (T2OUT)
/RS232-TX: J2.3, U6.8 (R2IN)
/SCK: D1.2 (A), J1.3 (SCK), U1.19 (PB5)
/SIPO_CLK: U1.15 (PB1), U2.11 (SRCLK), U3.11 (SRCLK), U9.11 (SRCLK)
/SIPO_O_1: U2.15 (QA)
/SIPO_O_2: U2.1 (QB)
/SIPO_O_7: R8.1, U2.6 (QG)
/SIPO_O_8: R7.1, U2.7 (QH)
/SIPO_O_9: R6.1, U3.15 (QA)
/SIPO_O_10: R5.1, U3.1 (QB)
/SIPO_O_11: R4.1, U3.2 (QC)
/SIPO_O_12: R3.1, U3.3 (QD)
/SIPO_O_13: R2.1, U3.4 (QE)
/SIPO_O_14: R1.1, U3.5 (QF)
/SIPO_RCLK: U1.23 (PC0), U2.12 (RCLK), U3.12 (RCLK), U9.12 (RCLK)
/SIPO_SER: U1.14 (PB0), U2.14 (SER)
/SW_12V: D3.2 (A), SW2.2 (B)
/TTL-RX: U1.2 (PD0), U6.9 (R2OUT)
/TTL-TX: U1.3 (PD1), U6.10 (T2IN)
/XTAL1: C1.2, R18.2, U1.9 (PB6/XTAL1), Y1.2
/XTAL2: C2.2, R18.1, U1.10 (PB7/XTAL2), Y1.1
/~PISO_CLR: U1.4 (PD2), U8.9 (~R)
/~RESET: C3.1, J1.5 (~RST), R15.2, SW1.2, U1.1 (PC6/~RESET)
/~SIPO_CLR: U1.16 (PB2), U2.10 (~SRCLR), U3.10 (~SRCLR), U9.10 (~SRCLR)
/~SIPO_OE: U1.24 (PC1), U2.13 (~OE), U3.13 (~OE), U9.13 (~OE)
GND: C1.1, C2.1, C7.1, C8.2, C9.2, C10.2, C11.2, C12.2, C13.2, C14.2, C15.2, C16.2, C17.2, H1.1, H2.1, H3.1, H4.1, J1.6 (GND), J2.0 (PAD), J2.5, J3.2 (Ext), R16.2, R17.2, R19.2, R20.2, SW1.1, U1.8 (GND), U1.22 (AGND), U2.8 (GND), U3.8 (GND), U5.10 (GND), U6.11 (T1IN), U6.15 (GND), U7.2 (GND), U8.1 (SER), U8.8 (GND), U9.8 (GND), U10.12 (GND)
unnamed: C3.2, U6.12 (R1OUT)
unnamed: C4.1, U6.1 (C1+)
unnamed: C4.2, U6.3 (C1-)
unnamed: C5.1, U6.4 (C2+)
unnamed: C5.2, U6.5 (C2-)
unnamed: C6.1, U6.2 (VS+)
unnamed: C7.2, U6.6 (VS-)
unnamed: D1.1 (K), R16.1
unnamed: D2.1 (K), R17.1
unnamed: D4.1 (K), R19.1
unnamed: D4.2 (A), U1.27 (PC4)
unnamed: D5.1 (K), R20.1
unnamed: D5.2 (A), U1.28 (PC5)
unnamed: U2.9 (QH'), U3.14 (SER)
unnamed: U3.9 (QH'), U9.14 (SER)
VCC: C6.2, C8.1, C9.1, C10.1, C11.1, C12.1, C13.1, C14.1, C16.1, C17.1, J1.2 (VCC), R15.1, U1.7 (VCC), U1.20 (AVCC), U1.21 (AREF), U2.16 (VCC), U3.16 (VCC), U5.20 (VCC), U6.16 (VCC), U7.3 (OUT), U8.16 (VCC), U9.16 (VCC), U10.24 (VCC)

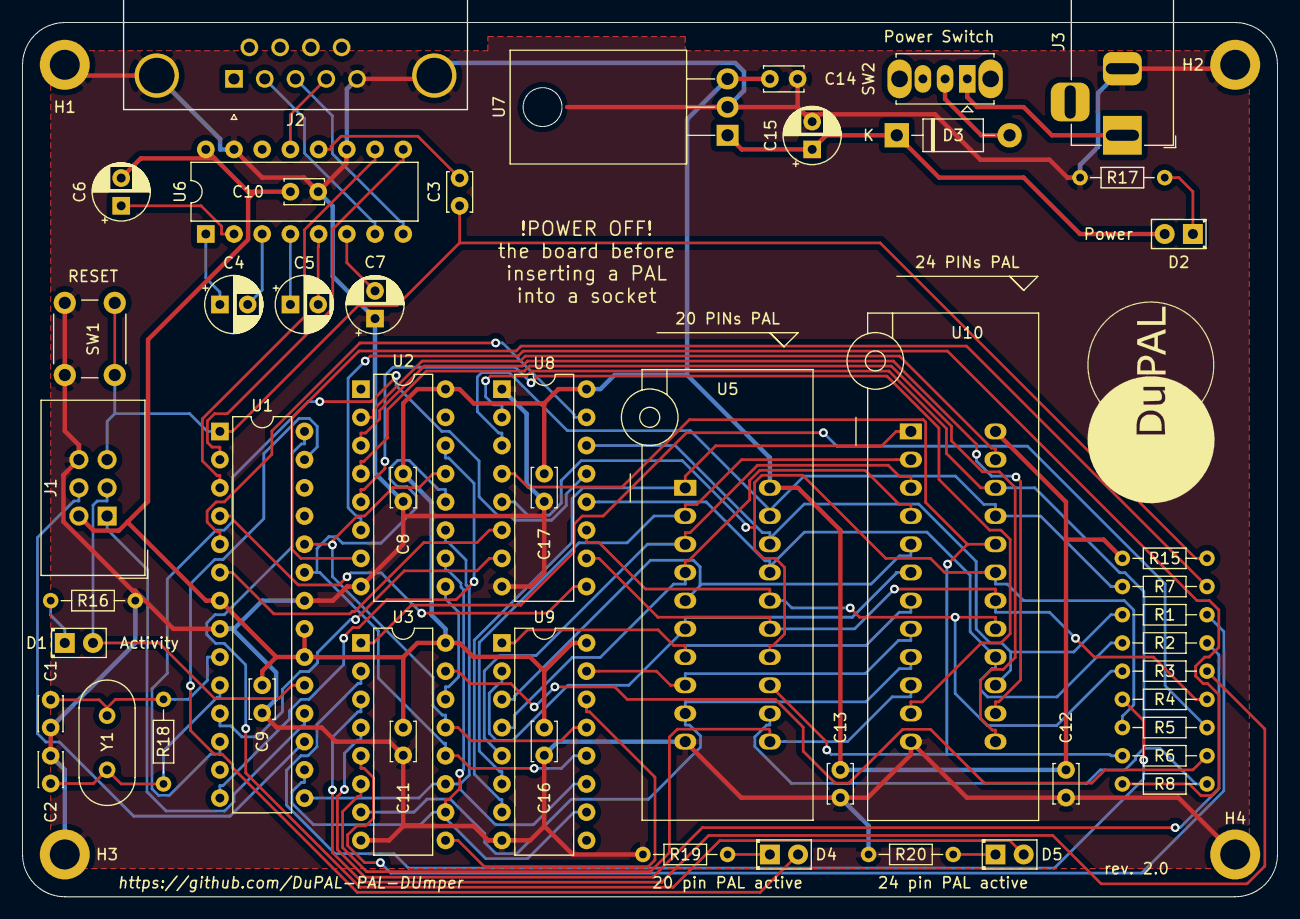
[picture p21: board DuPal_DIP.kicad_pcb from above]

Board: 2 copper layers, 113.0 x 78.7 mm, 55 parts (0 on the bottom side), 71 nets.

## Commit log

2020-02-25 Begin schematic
    [DuPal_DIP.kicad_pcb, DuPal_DIP.sch]
2020-02-25 Add DuPal schematics changes
    [DuPal_DIP.sch]
2020-02-25 Add oscillator
    [DuPal_DIP.sch]
2020-02-25 More schematis changes
    [DuPal_DIP.sch]
2020-02-25 Complete schematic of PAL dumper
    [DuPal_DIP.sch]
2020-02-26 Change wiring
    [DuPal_DIP.sch]
2020-02-26 Assigned footprints
    [DuPal_DIP.sch]
2020-02-26 Add correct footprints
    [DuPal_DIP.kicad_pcb, DuPal_DIP.sch]
2020-02-26 Organized board
    [DuPal_DIP.kicad_pcb]
2020-02-26 DuPAL project
    [DuPal_DIP.kicad_pcb]
2020-02-26 Add logo
    [DuPal_DIP.kicad_pcb]
2020-02-26 Add front silk text
    [DuPal_DIP.kicad_pcb]
2020-02-26 Add gerbers
    [DuPal_DIP.kicad_pcb]
2020-02-27 Distance some ICs
    [DuPal_DIP.kicad_pcb]
2020-08-11 Start writing the readme for the PCB board
2020-08-11 Update BOM
2020-08-15 Added PCB pics, added a TODO
2020-08-15 Add rev1.1 board
    [DuPal_DIP.kicad_pcb]
2020-08-16 Begin adding new shift and parallel registers
    [DuPal_DIP.sch]
2020-08-16 Begin remapping the connections
    [DuPal_DIP.sch]
2020-08-16 Slight cleanup
    [DuPal_DIP.sch]
2020-08-16 Begin connecting the new ICs in the circuit
    [DuPal_DIP.sch]
2020-08-16 Add 24 pin slot
    [DuPal_DIP.sch]
2020-08-16 Connected both PAL outputs
    [DuPal_DIP.sch]
2020-08-16 Reworked the outputs and added the inputs to the new PAL
    [DuPal_DIP.sch]
2020-08-16 Cleanup schematics, removed unused IC
    [DuPal_DIP.sch]
2020-08-16 Assign more footprints and names
    [DuPal_DIP.sch]
2020-08-16 Begin reworking the PCB
    [DuPal_DIP.kicad_pcb, DuPal_DIP.sch]
2020-08-16 First PCB model for Rev.2
    [DuPal_DIP.kicad_pcb, DuPal_DIP.sch]
2020-08-16 Add some silkscreen changes
    [DuPal_DIP.kicad_pcb]
2020-08-16 More silkscreen changes
    [DuPal_DIP.kicad_pcb]
2020-08-16 Add kicad files and pcb pic
    [DuPal_DIP.kicad_pcb]
2020-08-16 Updated silkscreen
    [DuPal_DIP.kicad_pcb]
2020-11-01 Updated the BOM
2021-11-02 Fix BOM list, missing C5
2021-11-08 Update README.md
    https://forum.kicad.info/t/warning-avoid-all-links-to-kicad-pcb-org-use-kicad-org/31521
2021-11-09 Update KiCad URL
2024-01-02 Update project, add schematics
    [DuPal_DIP.kicad_sch]
2024-06-16 Begin drawing V3 board
    [DuPal_V3.kicad_pcb, DuPal_V3.kicad_sch]
2024-06-16 Change resistor value
    [DuPal_V3.kicad_sch]
2024-06-16 Add connections to pico
    [DuPal_V3.kicad_sch]
2024-06-16 Add pulldown resistors for socket
    [DuPal_V3.kicad_sch]
2024-06-16 Change pulldown res on switched VCC value
    [DuPal_V3.kicad_sch]
2024-06-16 Added mounting holes
    [DuPal_V3.kicad_sch]
2024-06-16 Begin organizing the footprint
    [DuPal_V3.kicad_pcb]
2024-06-17 Some more placing on the PCB
    [DuPal_V3.kicad_pcb]
2024-06-17 More board placing
    [DuPal_V3.kicad_pcb]
2024-06-17 More placing
    [DuPal_V3.kicad_pcb]
2024-06-18 Update board
    [DuPal_V3.kicad_pcb, DuPal_V3.kicad_sch]
2024-06-18 More placements
    [DuPal_V3.kicad_pcb]
2024-06-21 Initial placement on board
    [DuPal_V3.kicad_pcb]
2024-06-21 First automatic routing of the board
    [DuPal_V3.kicad_pcb, DuPal_V3.kicad_sch]
2024-06-22 Update silkscreen
    [DuPal_V3.kicad_pcb, DuPal_V3.kicad_sch]
2024-06-26 Update silkscreen on the board
    [DuPal_V3.kicad_pcb]
2024-06-27 Gerbers for rev0
    [DuPal_V3.kicad_pcb]
2024-07-08 Add external pullup on /RELAY_ENABLE pin to avoid triggering at powerup
    [DuPal_V3.kicad_pcb, DuPal_V3.kicad_sch]
2024-07-09 Fix missing connection on a shifter
    [DuPal_V3.kicad_pcb, DuPal_V3.kicad_sch]
2024-07-13 Add pinheaders in schematic
    [DuPal_V3.kicad_pcb, DuPal_V3.kicad_sch]
2024-07-16 Add pinheaders to rev. 1 V3 board
    [DuPal_V3.kicad_pcb, DuPal_V3.kicad_sch]
2024-07-16 Move some silkscreen around
    [DuPal_V3.kicad_pcb]
2024-07-16 Allow usage of a 48pin zif dip
    [DuPal_V3.kicad_pcb, DuPal_V3.kicad_sch]
2024-07-16 Add silkscreen indication on where you should install a 42pin zif
    [DuPal_V3.kicad_pcb]
2024-07-22 Add gerbers for rev1 of dupal v3
    [DuPal_V3.kicad_pcb]
2024-07-22 Begin drawing a pod to read 1702/2708 eproms
    [pod_1701_2708.kicad_pcb, pod_1701_2708.kicad_sch]
2024-07-22 First sketch of the boarx
    [pod_1701_2708.kicad_pcb, pod_1701_2708.kicad_sch]
2024-07-22 Add automatic routing for pod
    [pod_1701_2708.kicad_pcb]
2024-07-23 Add pod for PAL devices
    [pod_pal.kicad_pcb, pod_pal.kicad_sch]
2024-07-26 Add rev.1 for the pal pod
    [pod_pal.kicad_pcb]
2024-07-26 Add schematics pdf for dupico, add pcbway sponsorship
2024-07-26 Renamed 1702A pod with correct name
    [pod_1702A_2708.kicad_pcb, pod_1702A_2708.kicad_sch]
2024-07-29 Begin cleaning up some egregious clearance rule violations
    [DuPal_V3.kicad_pcb]
2024-07-29 Avoid clearance violations, create rev.2 board for dupico
    [DuPal_V3.kicad_pcb]
2024-07-30 Update BOM for dupico
2024-07-30 Fix one entry in dupico BOM
2024-08-01 Fix BOM for dupico
2024-08-12 Update pal pod for dupico
    [pod_pal.kicad_pcb, pod_pal.kicad_sch]
2024-08-12 Fix rotated transistor in dupico pal pod
    [pod_pal.kicad_pcb, pod_pal.kicad_sch]
2024-08-13 Add PCBWay project link
2024-08-13 Update the README for the PAL POD linking PCBway shared project
2024-08-15 Fixed typos in BOM
    Changed R42, R46 - R85 resistor values to 470k as stated in schematics from the 10k that's listed.
    Changed SB74LV1T125DBV to SN74LV1T125DBV as found on Mouser
2024-08-18 Add eprom_01 board
    [eprom_01.kicad_pcb, eprom_01.kicad_sch]
2024-08-18 Shift the ZIF32 socket on the eprom_01 pod
    [eprom_01.kicad_pcb]
2024-09-03 Add schematics and gerbers
2024-09-03 Add PCBWay reference
2024-09-12 Fix EPROM pod power selection table
2025-02-17 Updated BOM for DuPAL V3 to include D1
2026-03-03 Fix a typo in BOM

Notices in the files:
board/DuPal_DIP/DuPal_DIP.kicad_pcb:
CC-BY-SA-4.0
